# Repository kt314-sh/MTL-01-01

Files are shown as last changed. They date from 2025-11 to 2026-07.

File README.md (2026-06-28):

<div align="center">
<h1>📡 MTL-1: High-Power LoRa Node</h1>
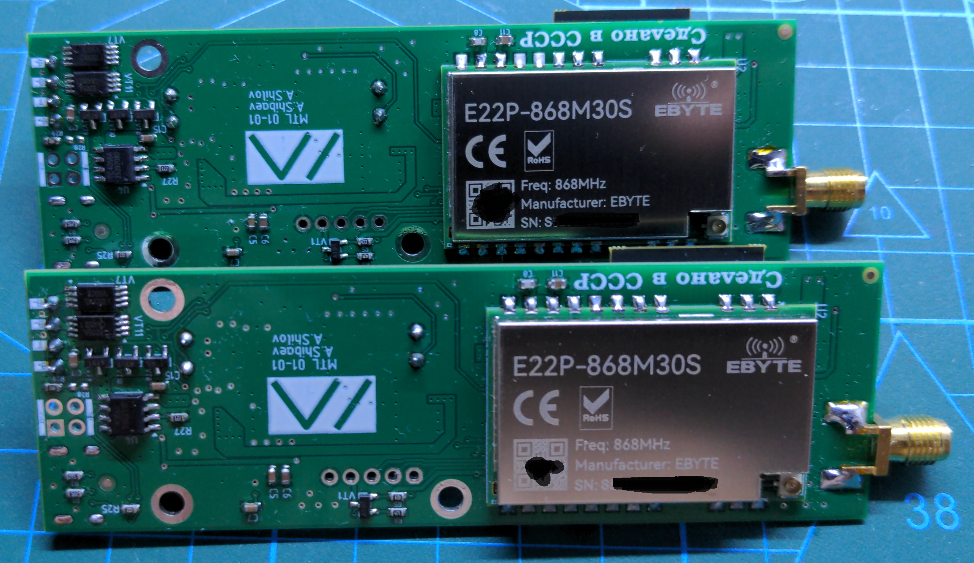
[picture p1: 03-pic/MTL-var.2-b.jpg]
 
  
<div align="left">
  
  # MTL-1
MTL-1 is a LoRa project based on ESP-32 s3 modules and [Ebyte](https://www.ebyte.com/) modules such as E22-xxxM30S, E22p-xxxM30S, E220-xxxM30S, E22-xxxM33S
Designed to work in [MeshCore](https://github.com/meshcore-dev ), [Meshtastic](https://github.com/meshtastic ), as a client and repeater.
- The project is almost fully compatible with Heltec v3, Heltec WSL3.
- 1A Standalone Linear Li-Ion Battery Charger
- Battery protection lithium-ion/polymer battery
- DC/DC up to 5V
- SMA connector
- GPIO
- 2 button. RESET, BOOT

 The device has proven itself well as a repeater and bridge 868/433
 
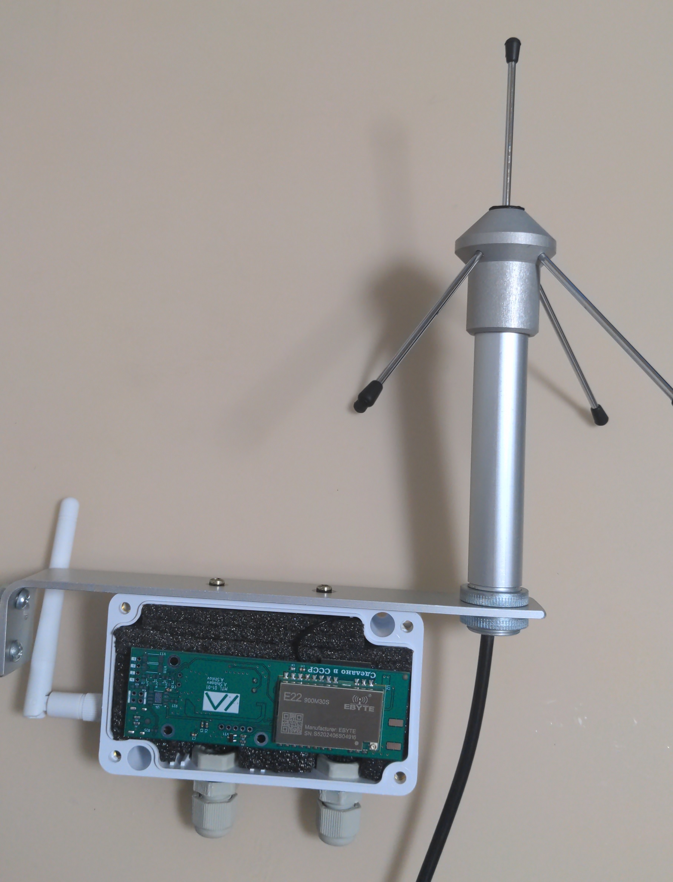
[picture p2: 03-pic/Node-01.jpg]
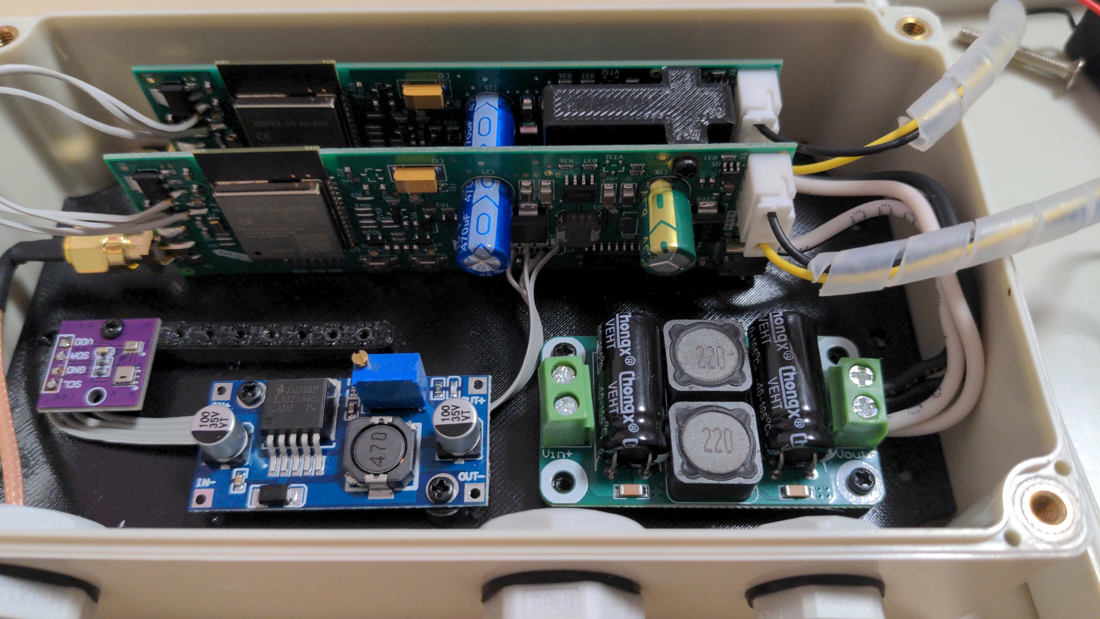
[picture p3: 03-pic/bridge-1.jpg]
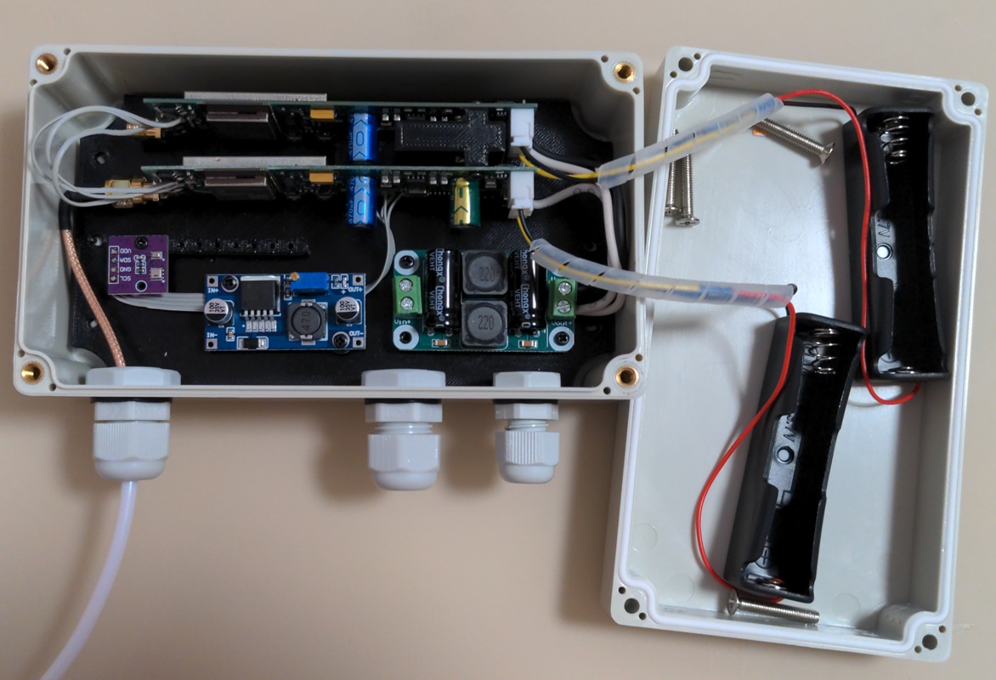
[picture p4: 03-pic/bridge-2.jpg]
    

### MTL-1 is available in three versions

#### Version 1. (not tested)
Support for Li-ion battery. When powered by USB, the DC Up converter is disconnected, and the e22 module receives a voltage of ~4.6V. When powered by the battery, DC Up is activated, and the e22 module receives a voltage of 5v.

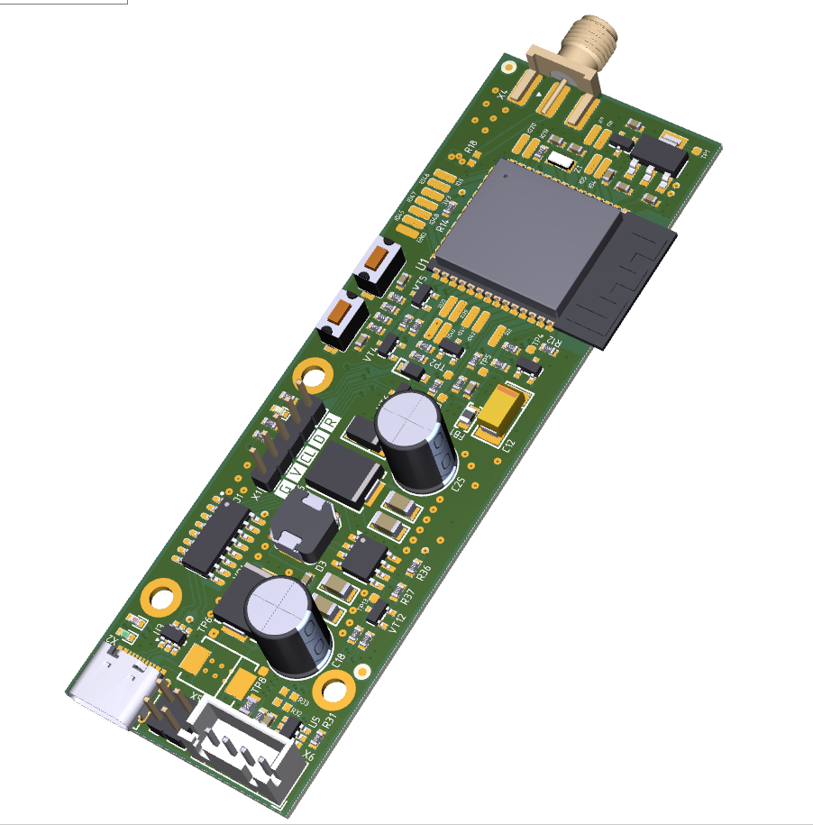
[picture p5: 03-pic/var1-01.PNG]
ver1T
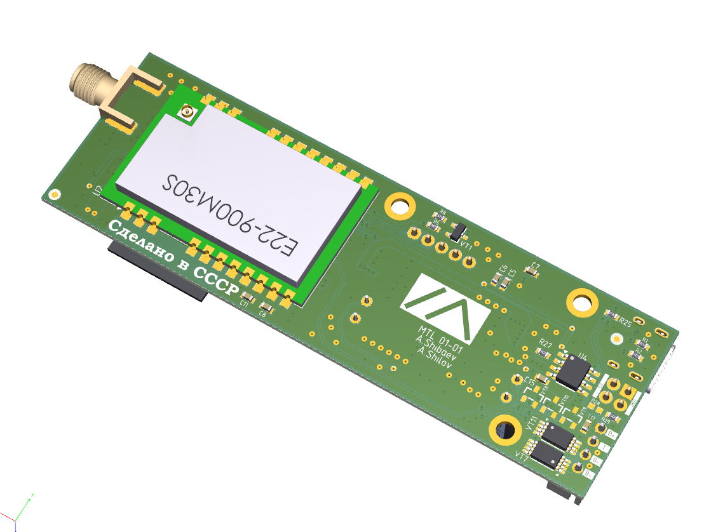
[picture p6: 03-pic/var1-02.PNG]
ver1B
 

#### Version 2
Support for Li-ion battery. When powered by USB, the DC Up converter is activated, and the e22 module receives a voltage of 5v. When powered by the battery, DC Up is activated, and the e22 module receives a voltage of 5v.

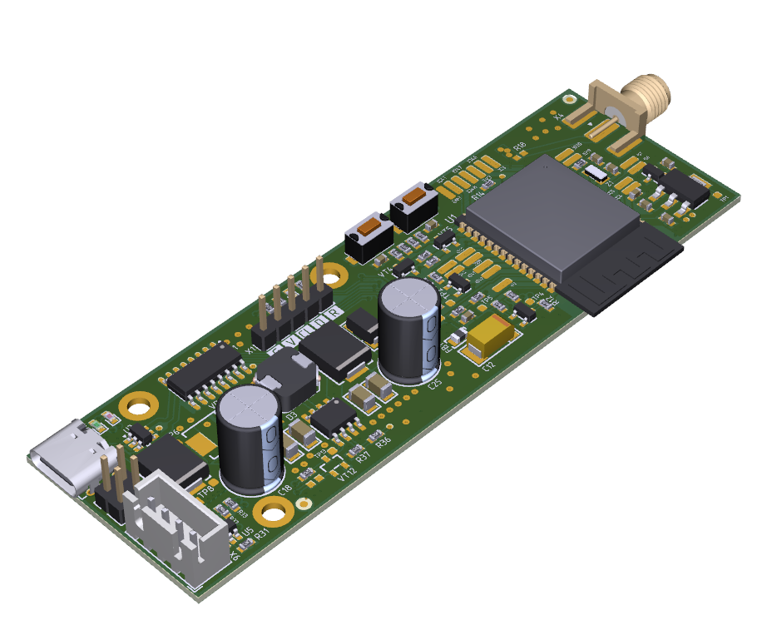
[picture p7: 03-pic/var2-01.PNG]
ver2T
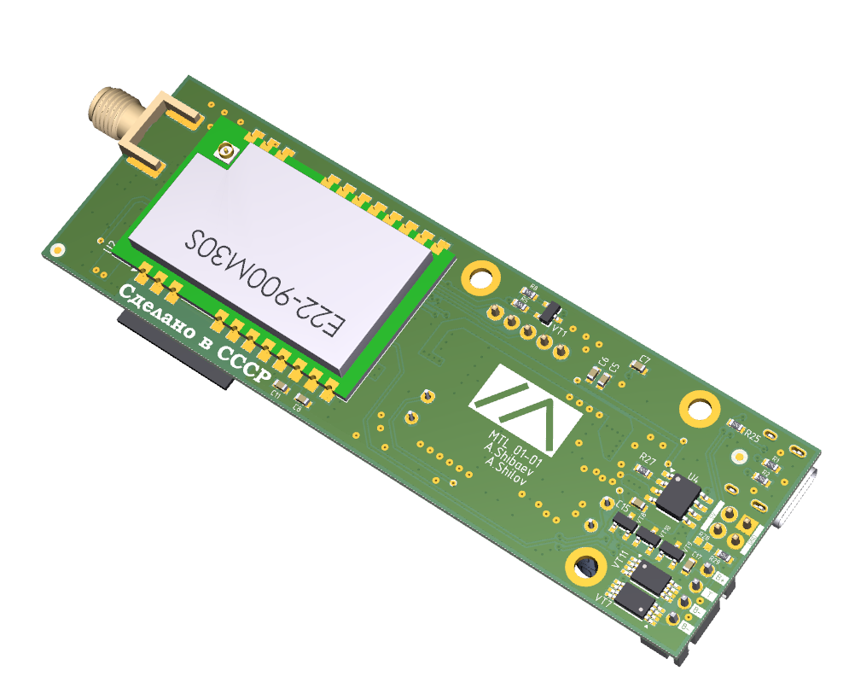
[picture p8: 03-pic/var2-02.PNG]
ver2B
 

#### Version 3
There is no Li-Ion battery support. When powered by USB, the e22 module receives a voltage of ~4.6V.

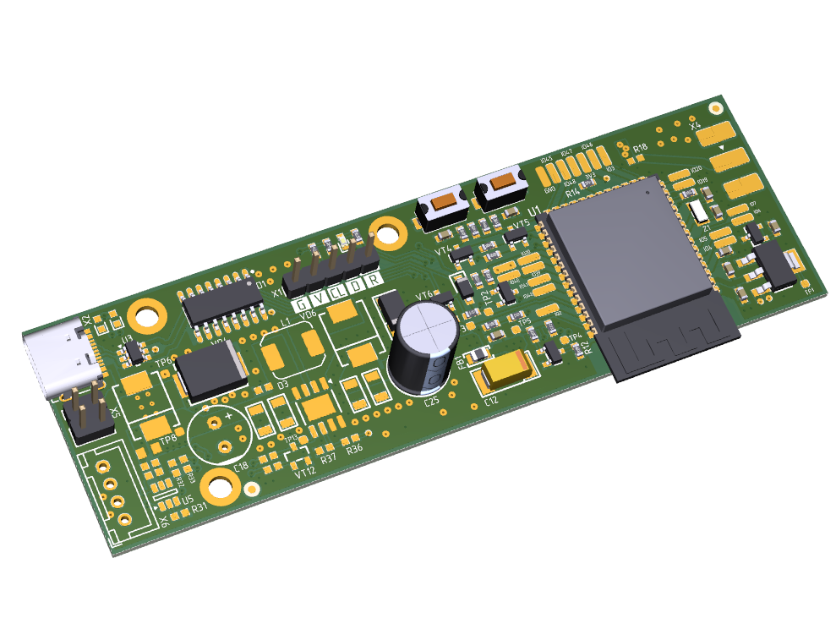
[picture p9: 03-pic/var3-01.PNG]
ver3T
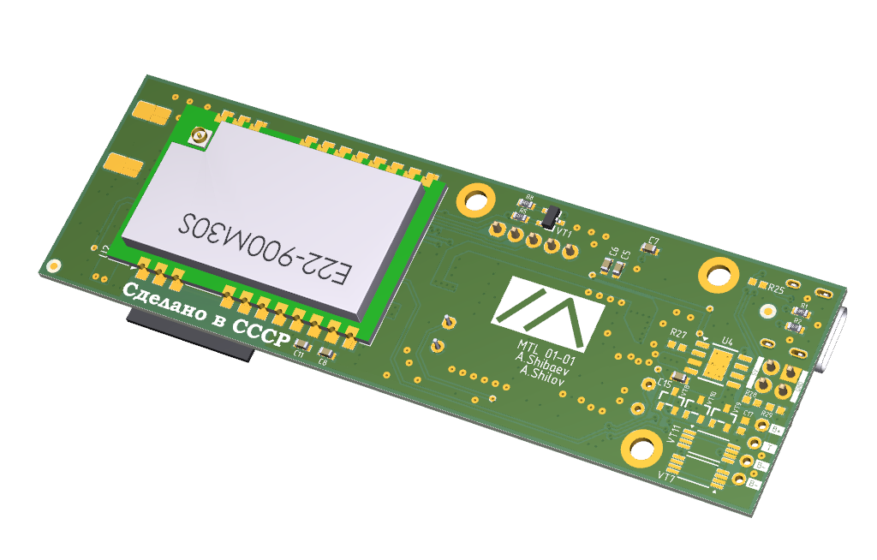
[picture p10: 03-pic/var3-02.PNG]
ver3B
 

### Power supply
The main power supply of the MTL-1 is provided via the "USB-C" or "X5" connectors, with a voltage of 5V, the recommended power supply current is 1.5...2A

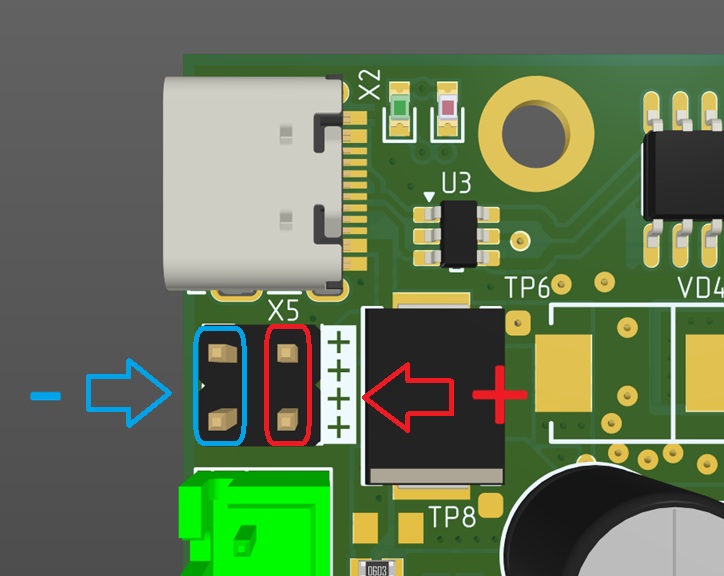
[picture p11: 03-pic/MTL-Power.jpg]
mtl1pwr


### Connecting a 3.7V Li-Ion battery (Version 1&2)
- To connect a battery without protection, use the "X6" connector. Maximum battery charge current 1A

- In the case of using a battery with protection, it is necessary to connect the +battery to the "Battery+" connector "X6", and the -battery to the "-" connector "X5".

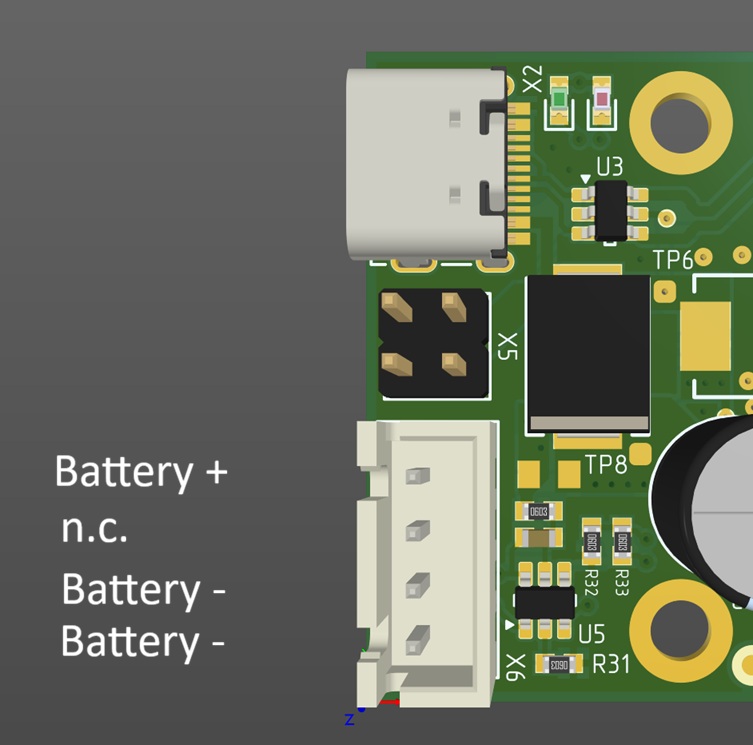
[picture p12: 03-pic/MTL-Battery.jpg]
mtlbtr


### Additional IO
Available IO: 2, 3, 4, 5, 6, 7, 19, 20, 38, 39, 40, 41, 42, 45, 46, 47, 48

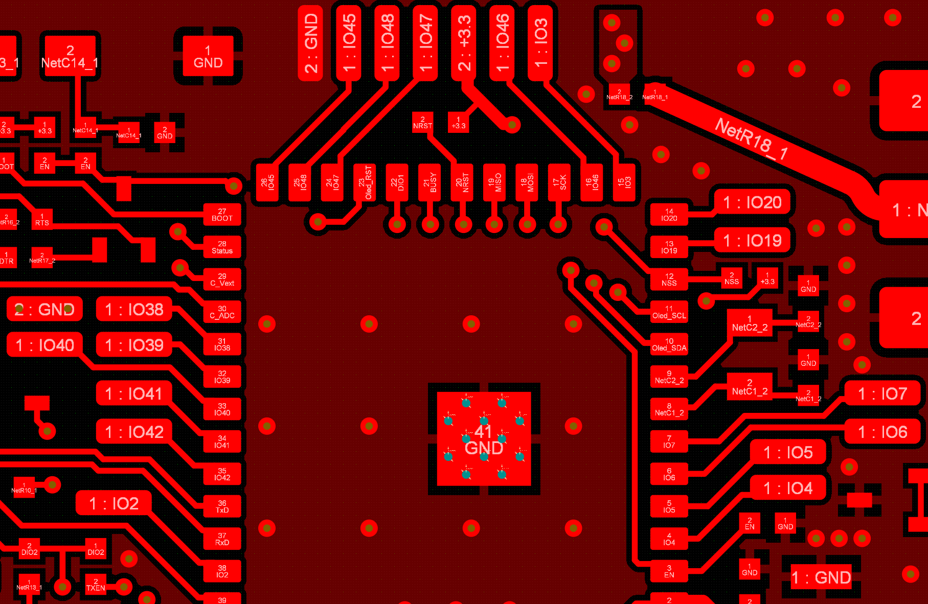
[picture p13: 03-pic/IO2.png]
mtlio1
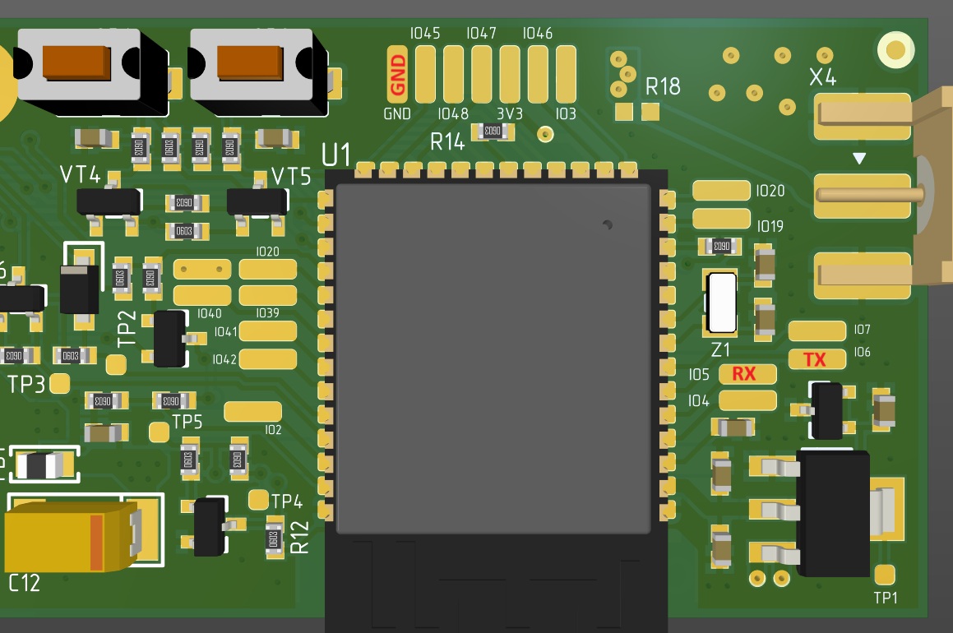
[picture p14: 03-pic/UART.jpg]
mtluart
 

### Connecting the antenna to IPEX
To use IPEX, the "R18" jumper must be removed

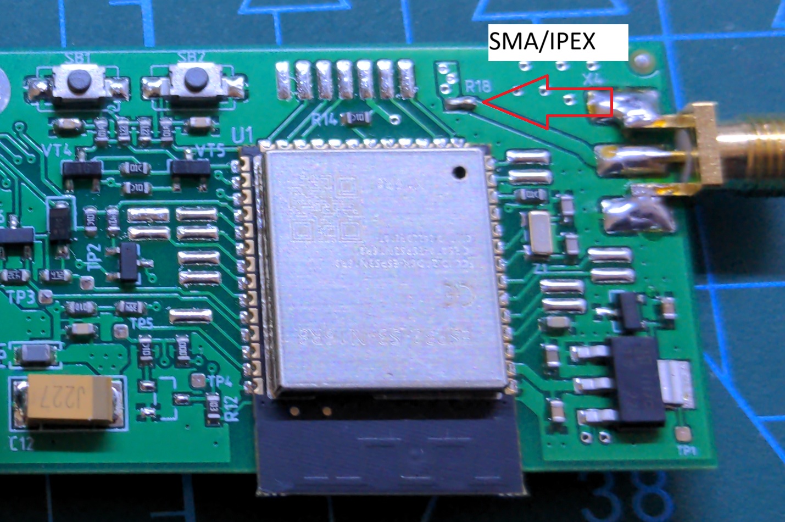
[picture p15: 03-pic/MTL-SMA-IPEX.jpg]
mtlsmaipex
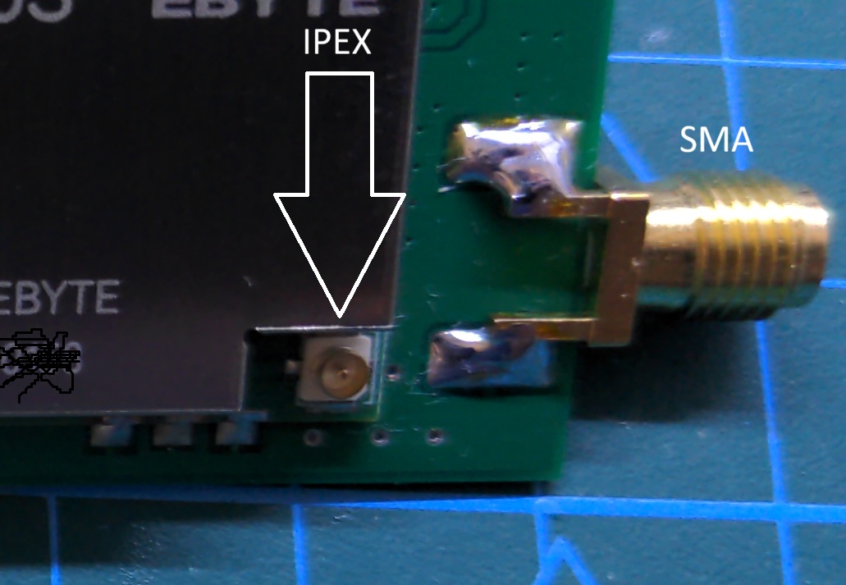
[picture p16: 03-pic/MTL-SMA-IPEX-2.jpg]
mtlsmaipex2
  

### Connecting an Oled display (SSD1306)
- G	GND
- V	+3.3v (Vcc)
- CL	i2c-SCL
- D	i2c-SDA

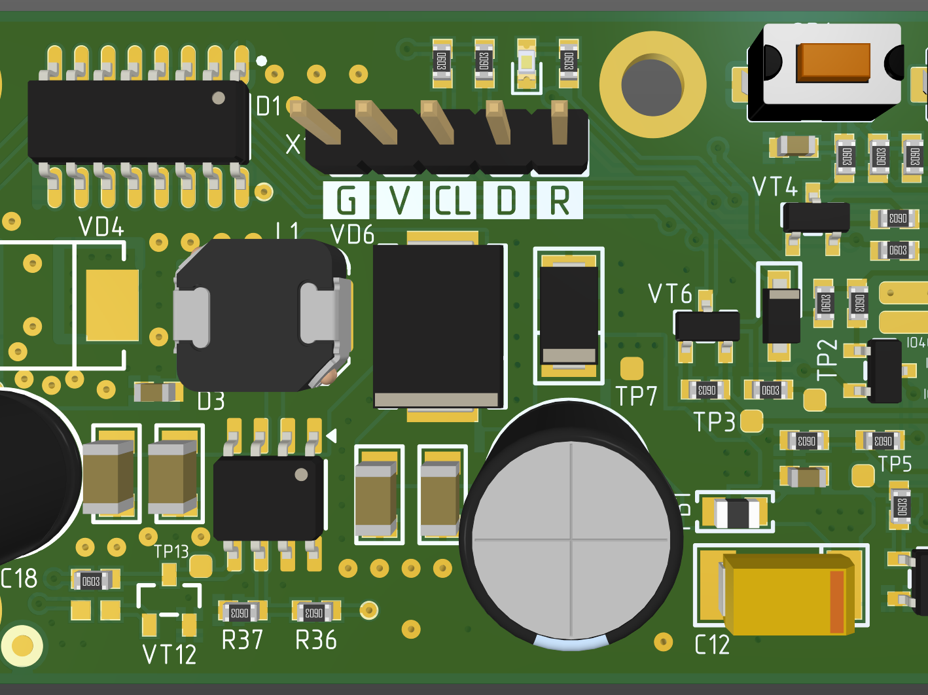
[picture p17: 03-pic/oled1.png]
mtloled1
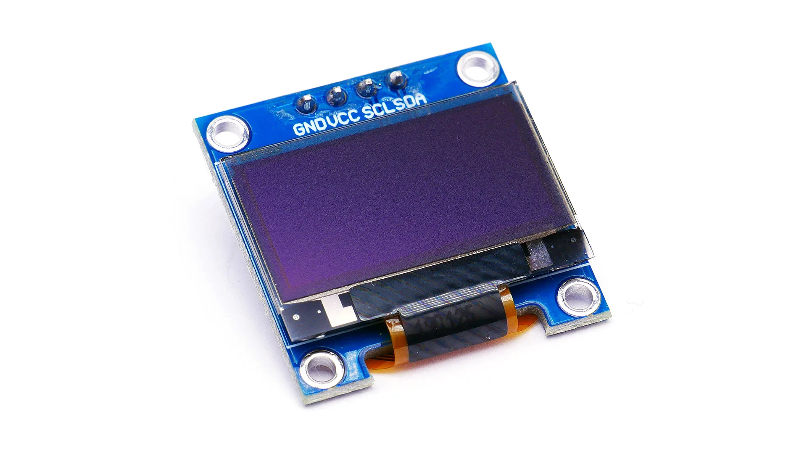
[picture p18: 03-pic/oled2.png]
mtloled2
  

### Driver CH340

Download driver [CH340.exe](https://www.wch-ic.com/downloads/CH341SER_EXE.html) [CH340.zip](https://www.wch-ic.com/downloads/CH341SER_ZIP.html) or [Github](https://github.com/jayfourjavier/INSTALL-CH340-ON-WINDOWS-11)

### Frequency range
#### 150-170Mhz
- e22-170m30s    SX1268  30dBm

#### 430Mhz
- e22p-433m30s   SX1268          30dBm
- e22-400m30s    SX1262, SX1268  30dBm (If S1262 Compatible with Heltec v3, Heltec WSL3)
- e22-400m33s    SX1268          33dBm
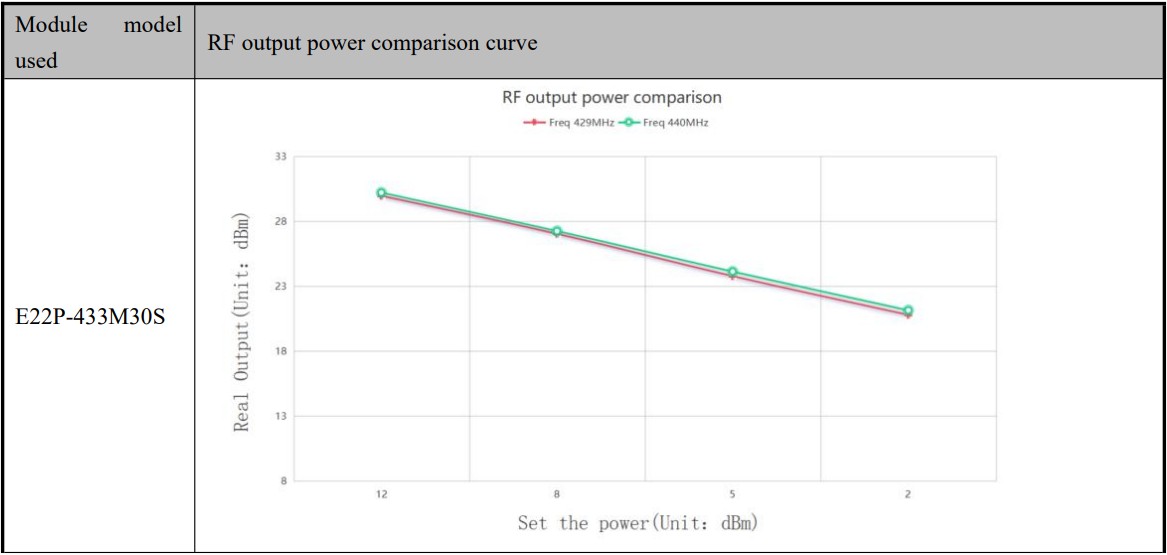
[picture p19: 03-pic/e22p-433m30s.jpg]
mtle22p433


#### 868-915Mhz
- e22p-868m30s   SX1262  31dBm  (Compatible with Heltec v3, Heltec WSL3)
- e22p-915m30s   SX1262  31dBm  (Compatible with Heltec v3, Heltec WSL3) 
- e22-900m30s    SX1262  30dBm  (Compatible with Heltec v3, Heltec WSL3)
- e22-900m33s    SX1262  33dBm

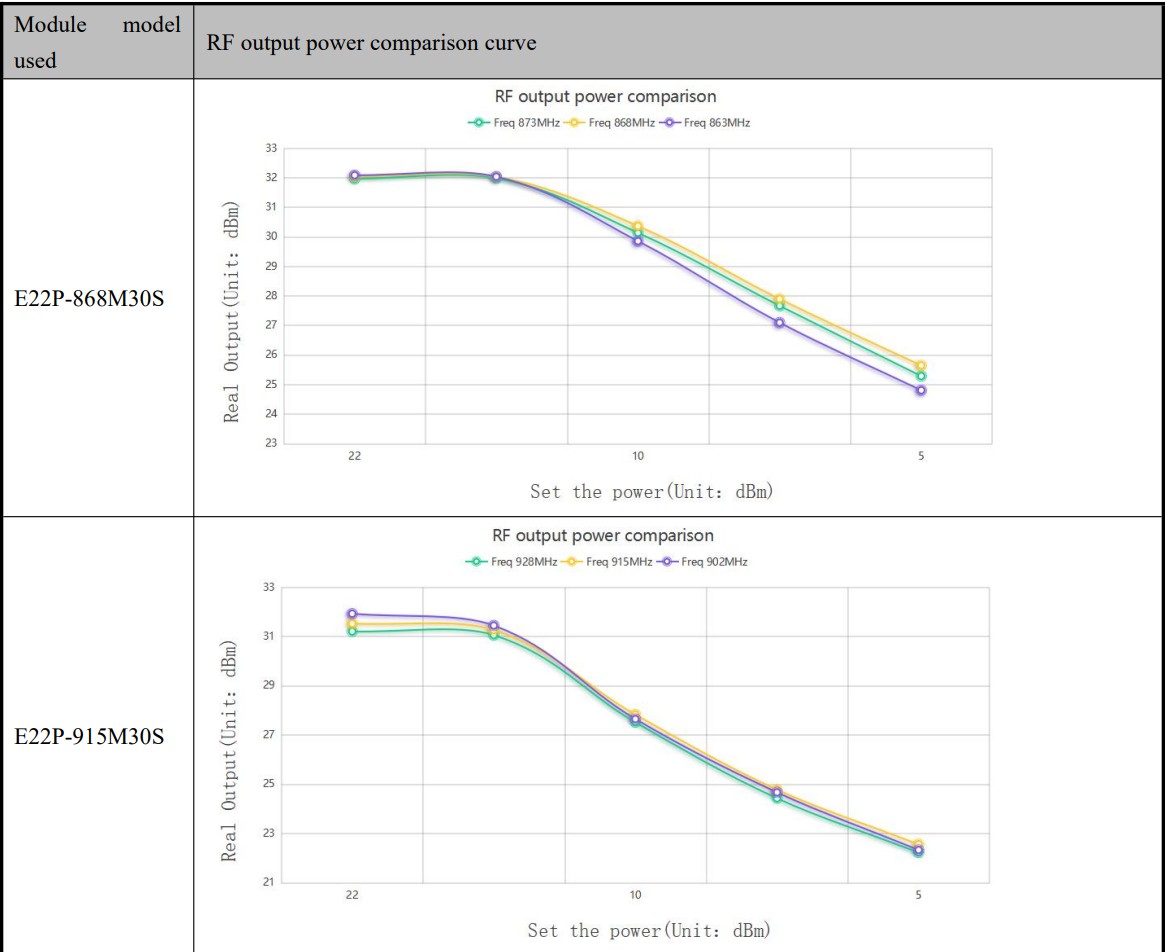
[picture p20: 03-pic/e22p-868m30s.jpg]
mtle22p868


### Case

- А good sealed casing made of Plastic sewer pipe with a diameter of 40-50mm
- The rainproof modem box VT-BOX9 with the antenna MOXON
- Rainproof case for Bridge Z10-7 158х90х60

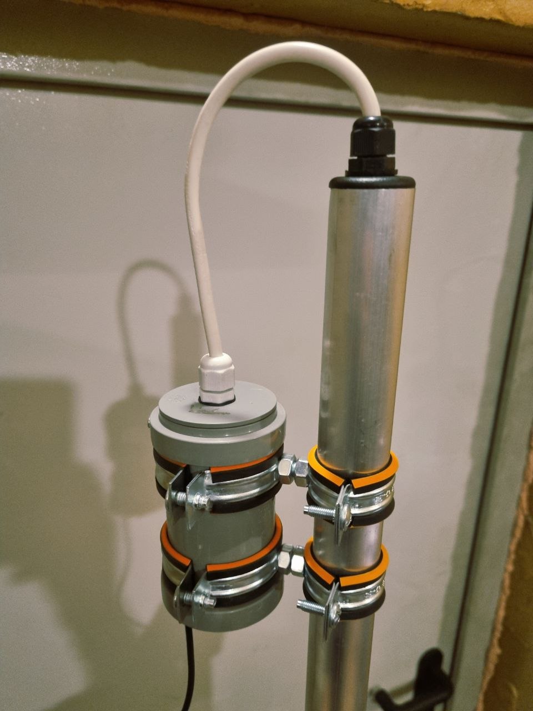
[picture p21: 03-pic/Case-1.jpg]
case1
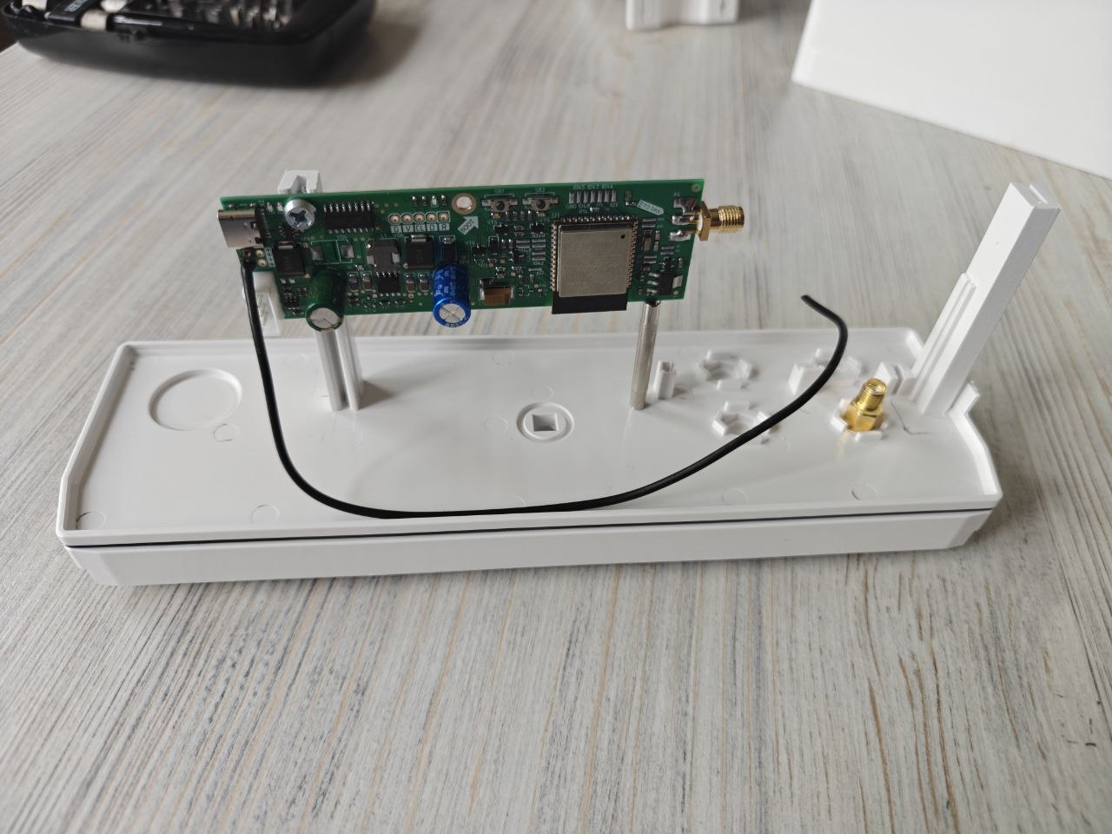
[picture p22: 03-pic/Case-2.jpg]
case2
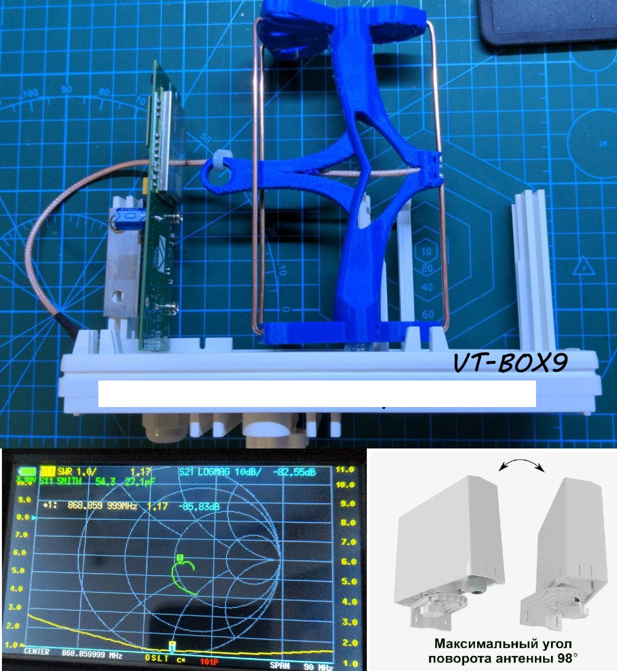
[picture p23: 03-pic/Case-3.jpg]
case3
  

### Repiters in use

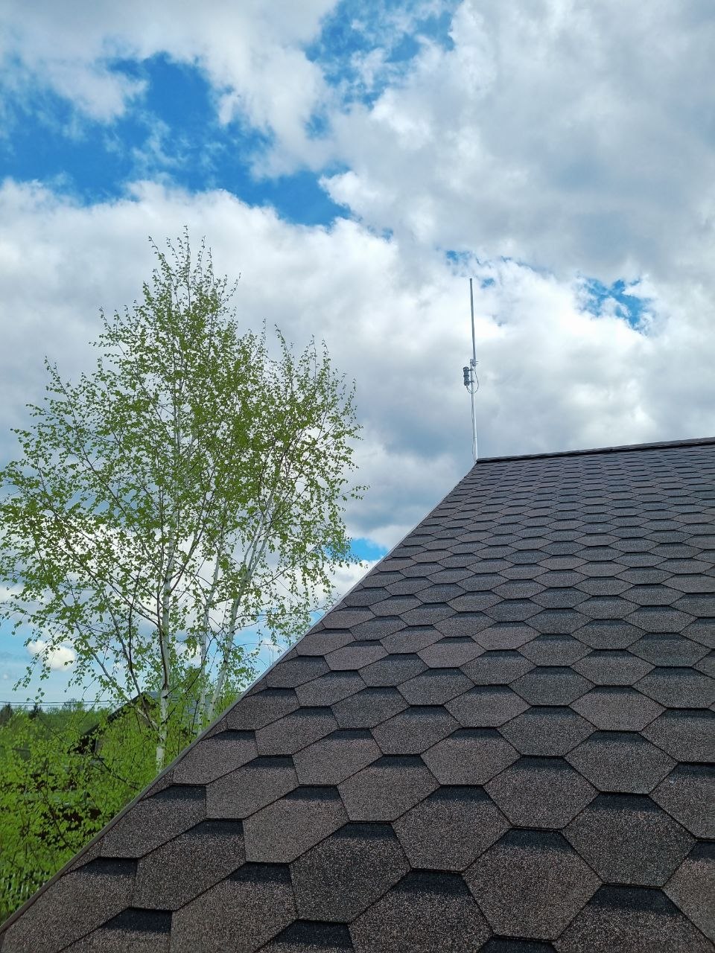
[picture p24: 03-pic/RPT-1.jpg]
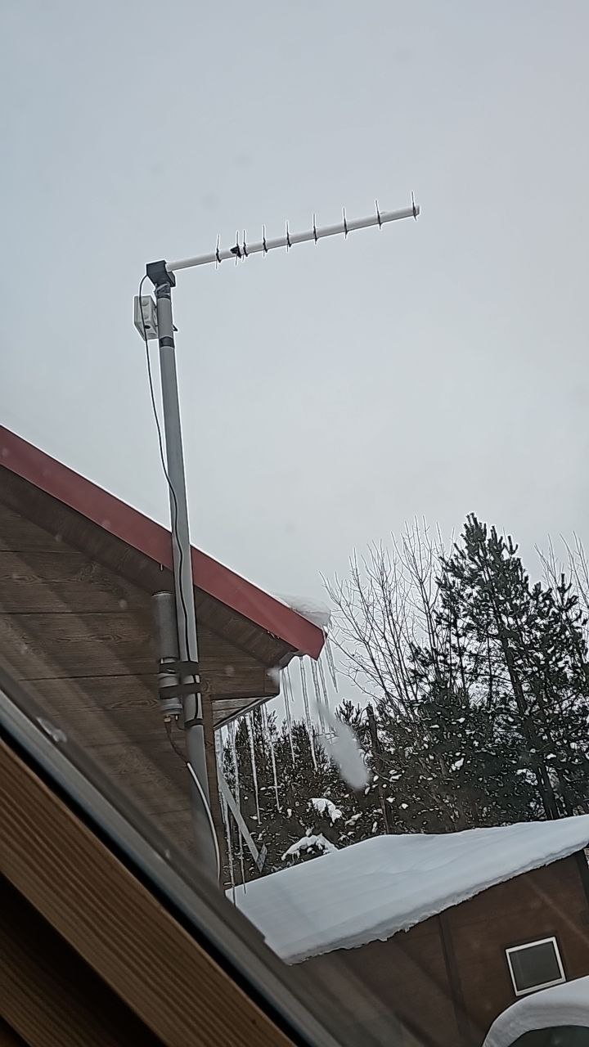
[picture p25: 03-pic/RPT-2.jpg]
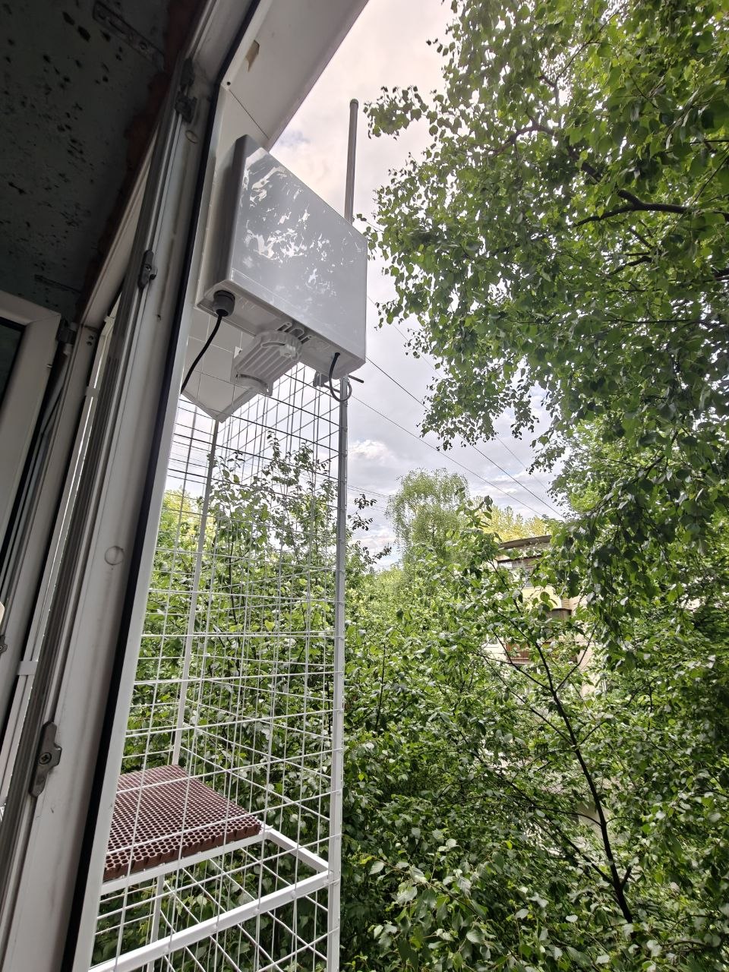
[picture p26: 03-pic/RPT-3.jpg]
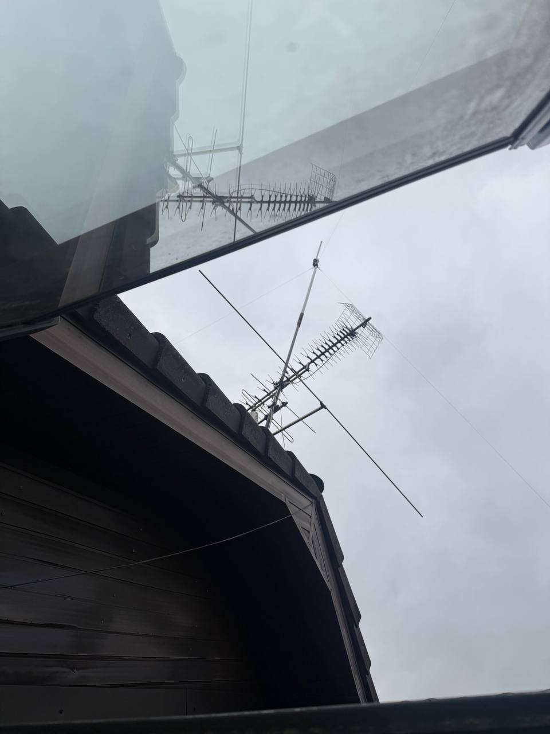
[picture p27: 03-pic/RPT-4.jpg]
rpt4
   

## Documentation
- GERBER [files](\01-PCB\Fabrication)
- Pick and Place [files](\01-PCB)
- Interactive scheme [BoM](\01-PCB)
- Datasheet [files](\02-datasheet)
- 3d model [STEP files](\04-3dmod)
- Mounting plate for case [Z10-7 158х90х60](\05-case\01-bridge)
- Instructions [RU](MTL-1_manual_04.2026.pdf)

### MeshCore SPB
- [MeshCore SPB](https://meshcore.spb.ru)
- [Telegram MeshCore SPB](https://t.me/meshcore_petersburg)

Additional description, see the link
https://github.com/vy52am0u/MTL

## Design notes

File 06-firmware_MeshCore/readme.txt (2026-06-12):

;add \variants\heltec_v3\target.h

#include <helpers/radiolib/CustomSX1268Wrapper.h>

;add \variants\heltec_v3\platformio.ini

[env:Heltec_v3_SX1268_repeater]
extends = Heltec_lora32_v3
build_flags =
  ${Heltec_lora32_v3.build_flags}
  -D USE_SX1268
  -D RADIO_CLASS=CustomSX1268
  -D WRAPPER_CLASS=CustomSX1268Wrapper
  -D DISPLAY_CLASS=SSD1306Display
  -D ADVERT_NAME='"MTL-1 433Mhz Repeater"'
  -D ADVERT_LAT=0.0
  -D ADVERT_LON=0.0
  -D ADMIN_PASSWORD='"password"'
  -D MAX_NEIGHBOURS=50
;  -D MESH_PACKET_LOGGING=1
;  -D MESH_DEBUG=1
  -D LORA_FREQ=433.0
  -D LORA_TX_POWER=12
build_src_filter = ${Heltec_lora32_v3.build_src_filter}
  +<helpers/ui/SSD1306Display.cpp>
  +<../examples/simple_repeater>
lib_deps =
  ${Heltec_lora32_v3.lib_deps}
  ${esp32_ota.lib_deps}
  bakercp/CRC32 @ ^2.0.0

[env:Heltec_v3_SX1268_repeater_bridge_rs232]
extends = Heltec_lora32_v3
build_flags =
  ${Heltec_lora32_v3.build_flags}
  -D USE_SX1268
  -D RADIO_CLASS=CustomSX1268
  -D WRAPPER_CLASS=CustomSX1268Wrapper
  -D DISPLAY_CLASS=SSD1306Display
  -D LORA_FREQ=433.0
  -D LORA_TX_POWER=12
  -D ADVERT_NAME='"MTL-1 UART Bridge"'
  -D ADVERT_LAT=0.0
  -D ADVERT_LON=0.0
  -D ADMIN_PASSWORD='"password"'
  -D MAX_NEIGHBOURS=50
  -D WITH_RS232_BRIDGE=Serial2
  -D WITH_RS232_BRIDGE_RX=5
  -D WITH_RS232_BRIDGE_TX=6
;  -D BRIDGE_DEBUG=1
;  -D MESH_PACKET_LOGGING=1
;  -D MESH_DEBUG=1
build_src_filter = ${Heltec_lora32_v3.build_src_filter}
  +<helpers/bridges/RS232Bridge.cpp>
  +<helpers/ui/SSD1306Display.cpp>
  +<../examples/simple_repeater>
lib_deps =
  ${Heltec_lora32_v3.lib_deps}
  ${esp32_ota.lib_deps}

[env:Heltec_v3_SX1268_repeater_bridge_espnow]
extends = Heltec_lora32_v3
build_flags =
  ${Heltec_lora32_v3.build_flags}
  -D RADIO_CLASS=CustomSX1268
  -D WRAPPER_CLASS=CustomSX1268Wrapper
  -D DISPLAY_CLASS=SSD1306Display
  -D LORA_FREQ=433.0
  -D LORA_TX_POWER=12
  -D DISPLAY_CLASS=SSD1306Display
  -D ADVERT_NAME='"MTL-1 ESPNow Bridge"'
  -D ADVERT_LAT=0.0
  -D ADVERT_LON=0.0
  -D ADMIN_PASSWORD='"password"'
  -D MAX_NEIGHBOURS=50
  -D WITH_ESPNOW_BRIDGE=1
;  -D BRIDGE_DEBUG=1
;  -D MESH_PACKET_LOGGING=1
;  -D MESH_DEBUG=1
build_src_filter = ${Heltec_lora32_v3.build_src_filter}
  +<helpers/bridges/ESPNowBridge.cpp>
  +<helpers/ui/SSD1306Display.cpp>
  +<../examples/simple_repeater>
lib_deps =
  ${Heltec_lora32_v3.lib_deps}
  ${esp32_ota.lib_deps}

[env:Heltec_v3_SX1268_companion_radio_usb]
extends = Heltec_lora32_v3
build_flags =
  ${Heltec_lora32_v3.build_flags}
  -I examples/companion_radio/ui-new
  -D RADIO_CLASS=CustomSX1268
  -D WRAPPER_CLASS=CustomSX1268Wrapper
  -D DISPLAY_CLASS=SSD1306Display
  -D LORA_FREQ=433.0
  -D LORA_TX_POWER=12
  -D MAX_CONTACTS=350
  -D MAX_GROUP_CHANNELS=40
  -D DISPLAY_CLASS=SSD1306Display
; NOTE: DO NOT ENABLE -->  -D MESH_PACKET_LOGGING=1
; NOTE: DO NOT ENABLE -->  -D MESH_DEBUG=1
build_src_filter = ${Heltec_lora32_v3.build_src_filter}
  +<helpers/ui/SSD1306Display.cpp>
  +<helpers/ui/MomentaryButton.cpp>
  +<../examples/companion_radio/*.cpp>
  +<../examples/companion_radio/ui-new/*.cpp>
lib_deps =
  ${Heltec_lora32_v3.lib_deps}
  densaugeo/base64 @ ~1.4.0

[env:Heltec_v3_SX1268_companion_radio_ble]
extends = Heltec_lora32_v3
build_flags =
  ${Heltec_lora32_v3.build_flags}
  -I examples/companion_radio/ui-new
  -D RADIO_CLASS=CustomSX1268
  -D WRAPPER_CLASS=CustomSX1268Wrapper
  -D DISPLAY_CLASS=SSD1306Display
  -D LORA_FREQ=433.0
  -D LORA_TX_POWER=12
  -D MAX_CONTACTS=350
  -D MAX_GROUP_CHANNELS=40
  -D DISPLAY_CLASS=SSD1306Display
  -D BLE_PIN_CODE=123456   ; dynamic, random PIN
  -D AUTO_SHUTDOWN_MILLIVOLTS=3400
  -D BLE_DEBUG_LOGGING=1
  -D OFFLINE_QUEUE_SIZE=256
;  -D MESH_PACKET_LOGGING=1
;  -D MESH_DEBUG=1
build_src_filter = ${Heltec_lora32_v3.build_src_filter}
  +<helpers/ui/SSD1306Display.cpp>
  +<helpers/ui/MomentaryButton.cpp>
  +<helpers/esp32/*.cpp>
  +<../examples/companion_radio/*.cpp>
  +<../examples/companion_radio/ui-new/*.cpp>
lib_deps =
  ${Heltec_lora32_v3.lib_deps}
  densaugeo/base64 @ ~1.4.0

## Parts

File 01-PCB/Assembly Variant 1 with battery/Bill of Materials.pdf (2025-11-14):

Страница 1 из 3

Наименование проекта | MTL 01-01 | 14.11.2025 12:34
Исполнение | Variant 1 with battery
Manufacturer 1 | Name | Description | Designator | Quantity
Yageo Group | CC0603BRNPO9BN5R6 | Керамический ЧИП-конденсатор, 0603, 5.6 пФ, 50 В, NP0, 0.1pF | C1, C2 | 2
Yageo Group | CC0603KRX5R7BB475 | Керамический ЧИП-конденсатор, 0603, 4.7 мкФ, 16 В, X5R, 10% | C3, C5, C11, C17, C22 | 5
Yageo Group | CC0603JRX7R9BB104 | Керамический ЧИП-конденсатор, 0603, 100 нФ, 50 В, X7R, 5% | C4, C6, C7, C9, C15, C16 | 6
Yageo Group | CC0603JRNPO9BN102 | Керамический ЧИП-конденсатор, 0603, 1 нФ, 50 В, NP0, 5% | C8, C13, C14 | 3
Yageo Group | CC0603JRX7R9BB103 | Керамический ЧИП-конденсатор, 0603, 10 нФ, 50 В, X7R, 5% | C10 | 1
KEMET | T491C476K016AT | Танталовый ЧИП-конденсатор, типоразмер C, 47 мкФ, 16 В, 20% | C12 | 1
Hitano | EHR471M16BA | Конденсатор алюминиевый электролитический, 8x12 мм, 3.5 мм, 470 мкФ, 16 В, 20% | C18, C25 | 2
Samsung Electro-Mechanics | CL31B106KAHNNNE | Керамический ЧИП-конденсатор, 1206, 10 мкФ, 25 В, X7R, 10% | C19, C20, C23, C24 | 4
Samsung Electro-Mechanics | CL10B105KB8NQNC | Керамический ЧИП-конденсатор, 0603, 1 мкФ, 50 В, X7R, 10% | C21 | 1
WCH | CH340C | Интерфейс, преобразователь USB-UART | D1 | 1
Tae Jin Technology | LM1117GS-3.3 | Линейный стабилизатор, 3.3 В, 1 А | D2 | 1
XySemi | XR2981 | Повышающий DC/DC преобразователь, вх. 2.7..3.3 В, вых. 24 В | D3 | 1
Murata | BLM21PG121SH1D | Ферритовый ЧИП-фильтр, 0805, 120 Ом @ 100 МГц, 25%, 3 А, 30 мОм | FB1 | 1
HongliTronic | HL-PST-1608S22OC | Светодиод, 0603, оранжевый | HL1 | 1
Lite-On | LTST-C190KRKT | Светодиод, 0603, красный | HL2 | 1
HongliTronic | HL-PST-1608S11GC | Светодиод, 0603, зелёный | HL3 | 1
Yageo Group | RC0603FR-070RL | ЧИП-резистор, 0603, 0 Ом, 1%, 0.1 Вт | J1, R29 | 2
TDK | SPM6530T-2R2M | Индуктивность проволочная, SPM6530, 2.2 мкГн @ 100 кГц, 8.2 А, 20%, 19.1 мОм | L1 | 1
Yageo | RC0603FR-075K1L | ЧИП-резистор, 0603, 5.1 кОм, 1%, 0.1 Вт | R1, R2 | 2
Yageo Group | RC0603FR-0710KL | ЧИП-резистор, 0603, 10 кОм, 1%, 0.1 Вт | R3-R6, R12-R17, R19, R20, R35 | 13
Yageo Group | RC0603FR-07470RL | ЧИП-резистор, 0603, 470 Ом, 1%, 0.1 Вт | R7-R9, R21, R22 | 5

Страница 2 из

3

Yageo | RC0603FR-07390KL | ЧИП-резистор, 0603, 390 кОм, 1%, 0.1 Вт | R10 | 1
Yageo Group | RC0603FR-07100KL | ЧИП-резистор, 0603, 100 кОм, 1%, 0.1 Вт | R11 | 1
Yageo Group | RC0603FR-074K7L | ЧИП-резистор, 0603, 4.7 кОм, 1%, 0.1 Вт | R23, R24, R34 | 3
Yageo Group | RC0603FR-071KL | ЧИП-резистор, 0603, 1 кОм, 1%, 0.1 Вт | R25, R31 | 2
Yageo Group | RC0603FR-07100RL | ЧИП-резистор, 0603, 100 Ом, 1%, 0.1 Вт | R26 | 1
Yageo Group | RC0603FR-071K2L | ЧИП-резистор, 0603, 1.2 кОм, 1%, 0.1 Вт | R27 | 1
Yageo Group | RC0805FR-070RL | ЧИП-резистор, 0805, 0 Ом, 1%, 0.125 Вт | R30 | 1
Yageo Group | RC0603FR-0733KL | ЧИП-резистор, 0603, 33 кОм, 1%, 0.1 Вт | R36 | 1
Yageo Group | RC0603FR-0711KL | ЧИП-резистор, 0603, 11 кОм, 1%, 0.1 Вт | R37 | 1
Diptronics | DTSM-31N-V | Кнопка тактильная, миниатюрная, SMD, 12 В, 50 мА | SB1, SB2 | 2
| ESP32-S3-WROOM-1 | Модуль связи | U1 | 1
| E22-900M30S | Приёмопередатчик LoRa | U2 | 1
STMicroelectro nics | USBLC6-2SC6 | Сборка защитная, TVS-диоды, 5.2 В | U3 | 1
TOPPOWER | TP4056-42-ESOP8 | Контроллер заряда | U4 | 1
PUOLOP | DW01A | Контроллер литий-ионного аккумулятора | U5 | 1
Nexperia | BAT54H | Диод Шоттки, 30 В, 200 мА | VD1 | 1
Yangjie Electronic Technology | SS54 | Диод Шоттки, 40 В, 5 А | VD4, VD6 | 2
Nexperia | PESD3V3S2UT | Сдвоенный однонаправленный ESD-диод, 3.3 В | VD5 | 1
Yangjie Electronic Technology | SMAJ5.0A | Однонаправленный TVS-диод, 5 В | VD7 | 1
Alpha & Omega Semiconductor | AO3401 | Транзистор, P-канал, -30 В, -4 А | VT1, VT2 | 2
Nexperia | BC847C | Транзистор, NPN, 45 В, 100 мА | VT3-VT5, VT12 | 4
Nexperia | BSS138P | Транзистор, N-канал, 60 В, 360 мА | VT6 | 1
Fortune Semiconductor | FS8205A | Транзисторная сборка, 2N-канальный, 20 В/5 А | VT7, VT11 | 2
Connfly | DS1021-1X5 | Вилка на плату однорядная, прямая, 5 контактов, шаг 2.54 мм | X1 | 1
Connfly | DS1144-07 | Разъём USB Type-C угловой, 16 контактов | X2 | 1
Connfly | DS1158-03-01SV | Разъём SMA | X4 | 1
Connfly | DS1021-2x2 | Вилка на плату двухрядная, прямая, 4 контакта, шаг 2.54 мм | X5 | 1
JST | B4B-XH-A | Вилка на плату, 4 контакта, шаг 2.5мм, серия XH | X6 | 1

Страница 3 из 3

NDK | NX3215SA-32.768K-STD-
MUA-8 | Резонатор кварцевый, 3215, 32.768 кГц, 12.5 пФ, 20ppm | Z1 | 1

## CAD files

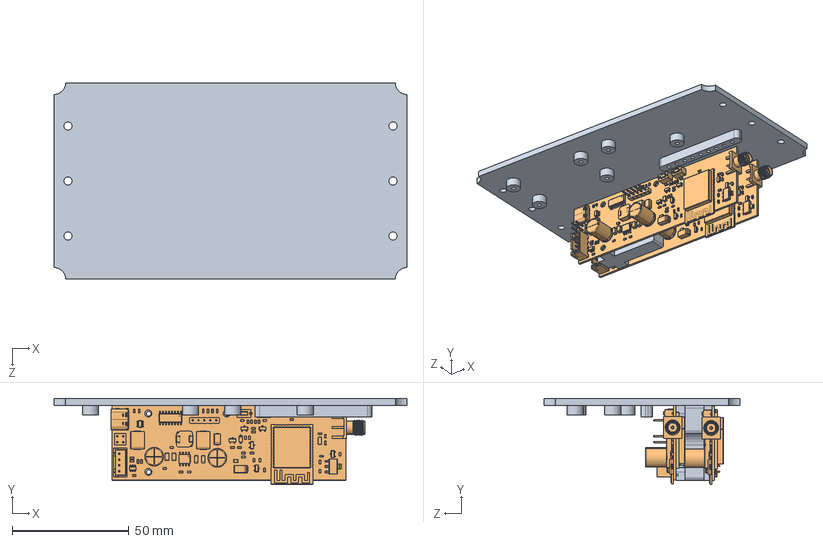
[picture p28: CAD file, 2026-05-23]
05-case/01-bridge/cad/Z10-7_158х90х60.SLDASM
151.0 x 36.8 x 84.0 mm
Шасси
MTL-01-01-var2.step x 2

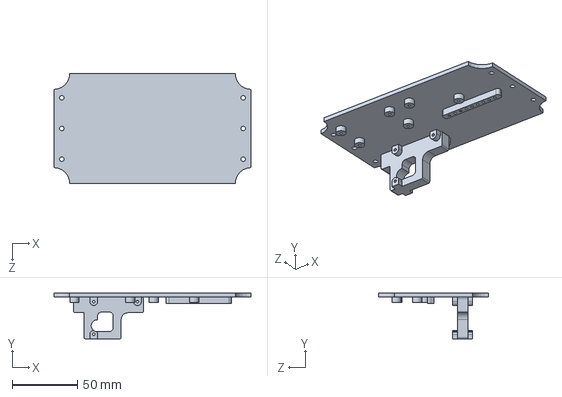
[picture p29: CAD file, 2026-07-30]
05-case/01-bridge/cad/Шасси2.SLDPRT
151.0 x 35.0 x 84.0 mm

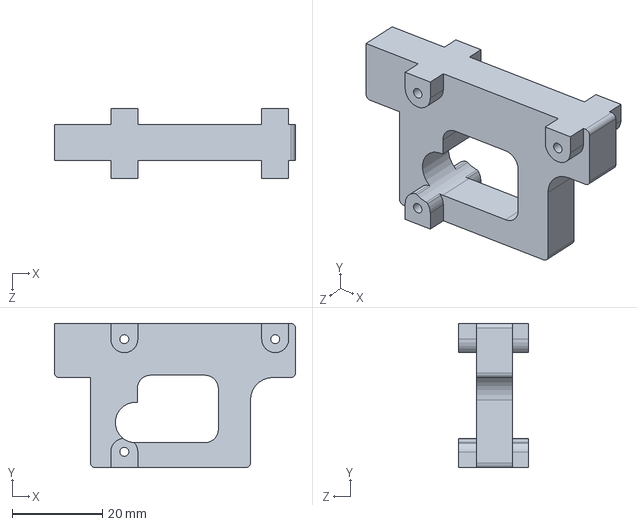
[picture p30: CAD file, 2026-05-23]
05-case/01-bridge/cad/Шасси1.SLDPRT
53.5 x 32.0 x 15.5 mm

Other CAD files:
05-case/01-bridge/cad/Шасси.SLDPRT
05-case/01-bridge/cad/Шасси2.STL
05-case/01-bridge/stl/Z10-7_158х90х60.3mf
05-case/01-bridge/stl/Z10-7_158х90х60.STL
05-case/01-bridge/stl/Шасси1.STL

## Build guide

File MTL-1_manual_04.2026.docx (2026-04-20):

# MTL-1


Содержание

1. Описание…………………………………………………………………….. 2
2. Подключение питания………………………………………………… 4
3. Подключение АКБ……………..………………………………………… 5
4. Дополнительные вводы-выводы……………………………….. 6
5. Подключение антенны к IPEX…………….……………………….. 7
6. Подключение Oled дисплея………………………………………… 7
7. Установка драйвера…………………………………………………….. 8
8. Установка Meshcore через Web Flasher……………………….10
9. Установка Meshcore через Flash download tool…………..13

MTL-1 это обучающий проект LoRa, основан на модулях ESP-32 s3 и модулях таких как E22-xxxM30S, E22p-xxxM30S, E220-xxxM30S, E22-xxxM33S

Проект практически полностью совместим с Heltec v3, Heltec WSL3.

Документация на проект

https://github.com/kt314-sh/MTL-01-01

https://github.com/vy52am0u/MTL

MTL-1 Существует в трёх вариантах исполнения

Вариант 1. (не тестировался)

Поддержка Li-Ion АКБ. При питании от USB, преобразователь DC Up отключен, на модуль e22 поступает напряжение ~4.6v. При питании от АКБ, DC Up задействован, на модуль e22 поступает напряжение 5v.

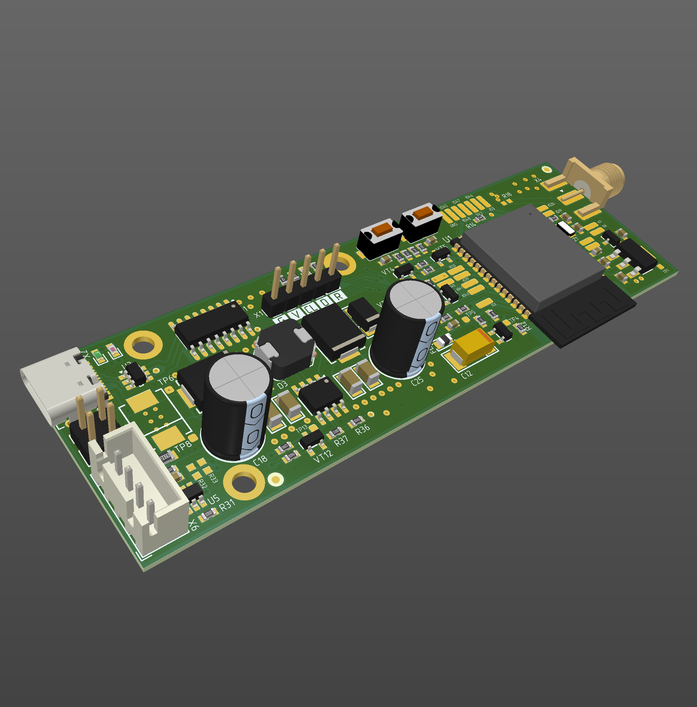
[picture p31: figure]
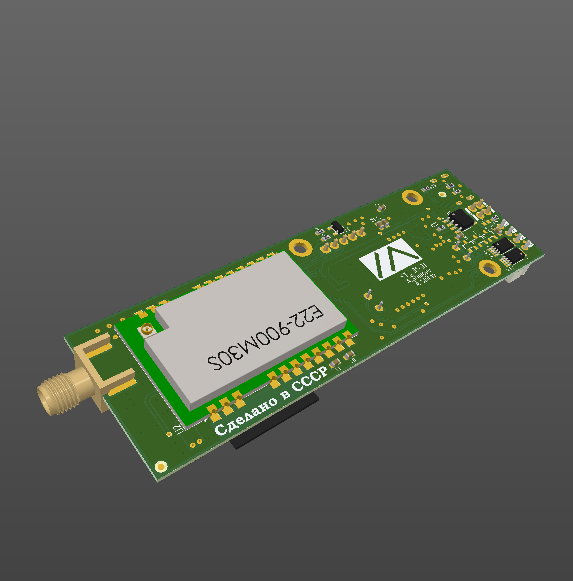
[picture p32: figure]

Вариант 2.

Поддержка Li-Ion АКБ. При питании от USB, преобразователь DC Up задействован, на модуль e22 поступает напряжение 5v. При питании от АКБ, DC Up задействован, на модуль e22 поступает напряжение 5v.

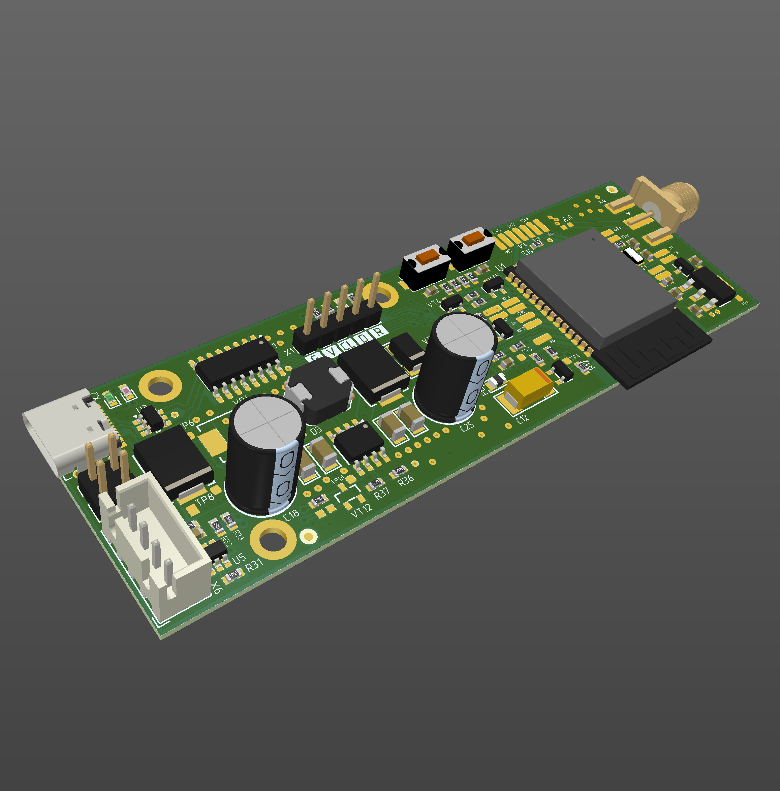
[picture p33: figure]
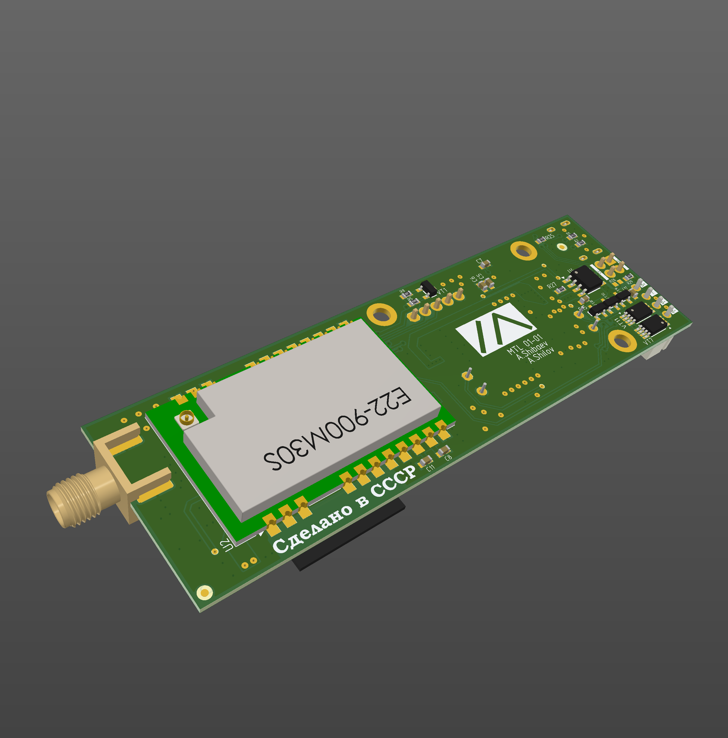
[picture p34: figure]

Вариант 3.

Отсутствует поддержка Li-Ion АКБ. При питании от USB, на модуль e22 поступает напряжение ~4.6v.

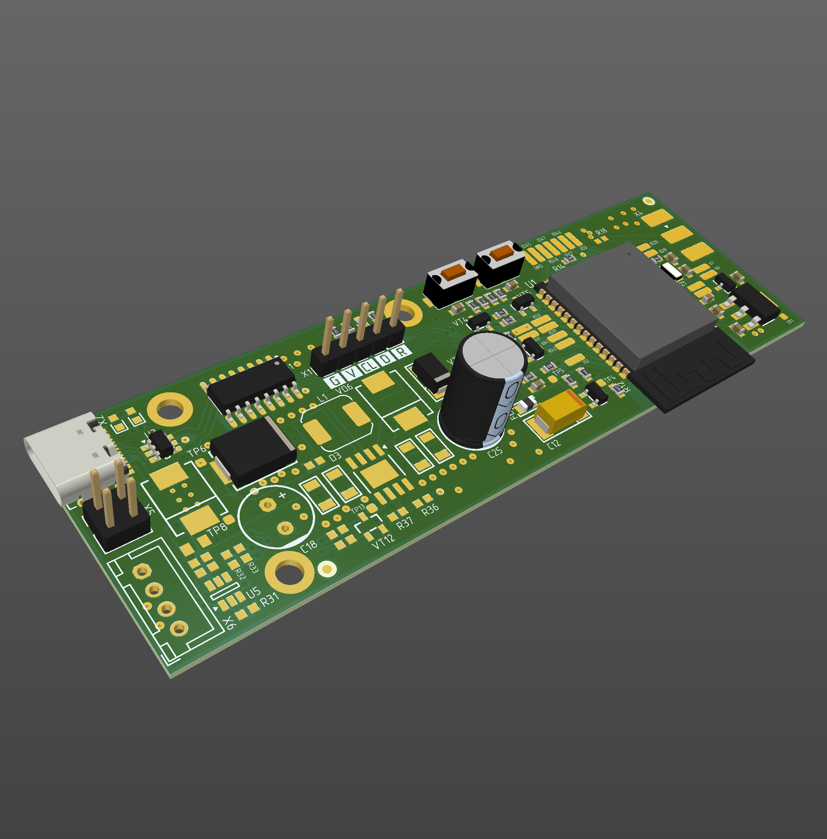
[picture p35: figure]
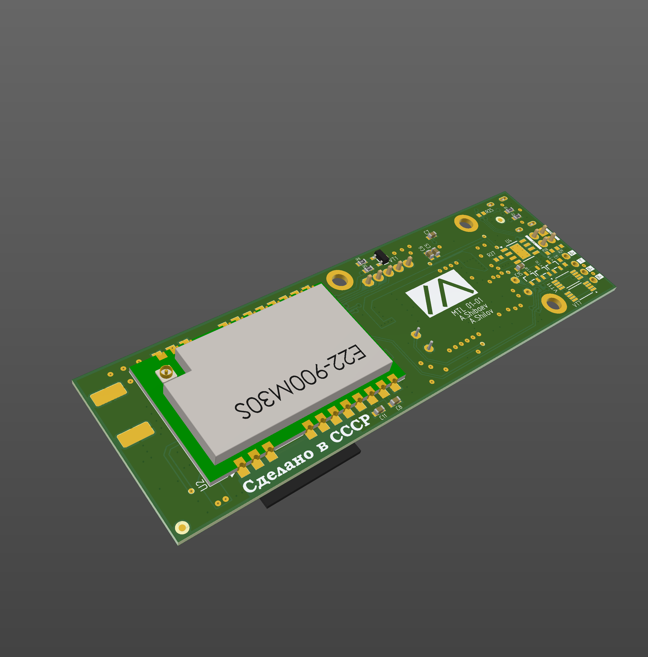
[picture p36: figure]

Подключение питания(Вариант 1,2,3)

Основное питание MTL-1 осуществляется через разъемы «USB-C» либо «X5», напряжением 5В, рекомендуемый ток источника питания 1.5...2А

Подключение Li-Ion АКБ 3.7В (Вариант 1,2)

Для подключения АКБ без защиты, используем разъему «X6». Максимальный ток заряда АКБ 1А

В случае использования АКБ с защитой, то необходимо подключить +АКБ к «Battery+» разъема «X6», а -АКБ к «-» разъема «X5».

Дополнительные IO

Доступные IO 2, 3, 4, 5, 6, 7, 19, 20, 38, 39, 40, 41, 42, 45, 46, 47, 48

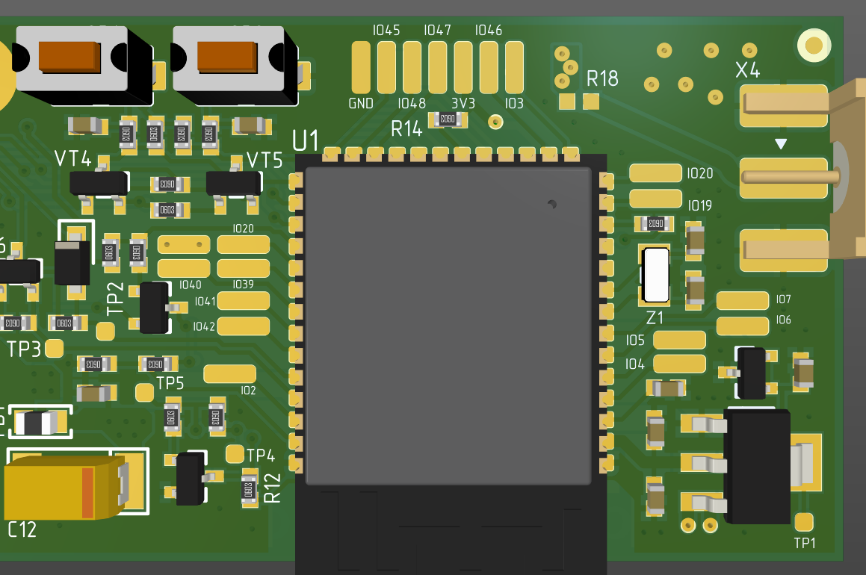
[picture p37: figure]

Подключение антенны к IPEX

Для использования IPEX, необходимо удалить перемычку «R18»

Подключение Oled дисплея (SSD1306)

G GND

V +3.3v (Vcc)

CL i2c-SCL

D i2c-SDA

Установка драйвера

1. Скачайте драйвер СH340

https://www.wch-ic.com/downloads/CH341SER_EXE.html

https://www.wch-ic.com/downloads/CH341SER_ZIP.html

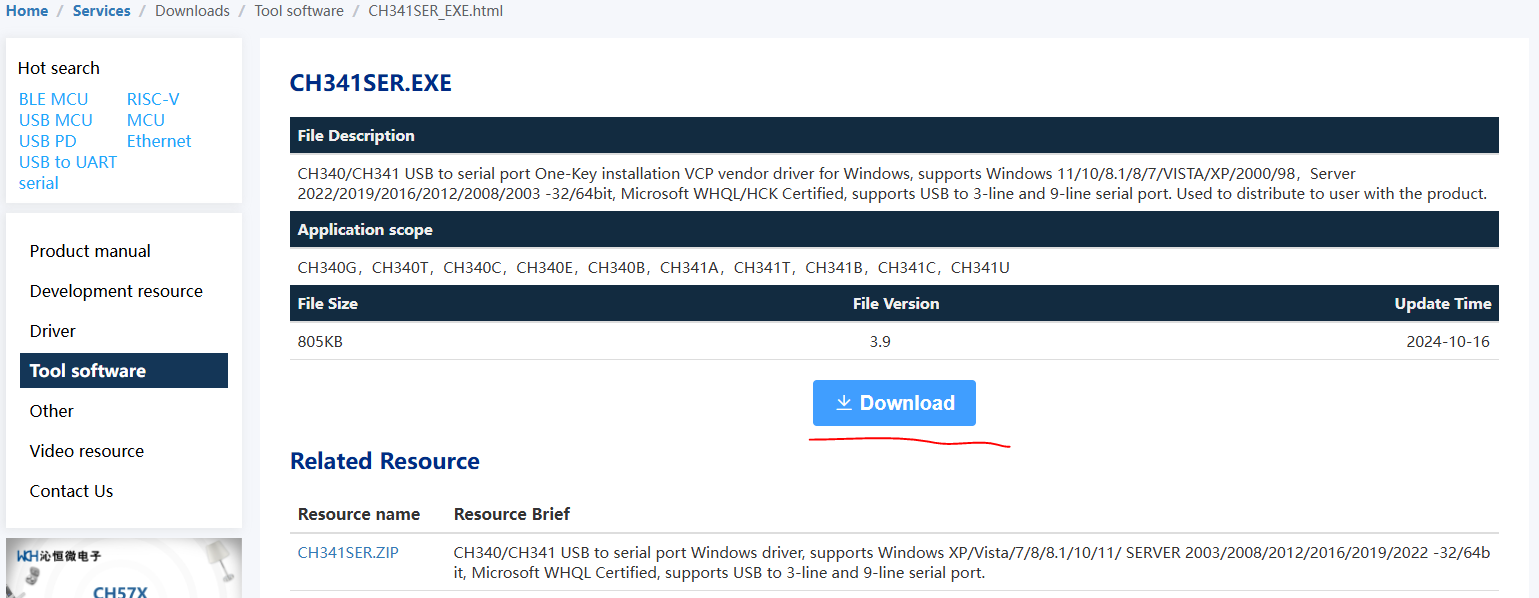
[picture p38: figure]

Или с Git Hub

https://github.com/jayfourjavier/INSTALL-CH340-ON-WINDOWS-11

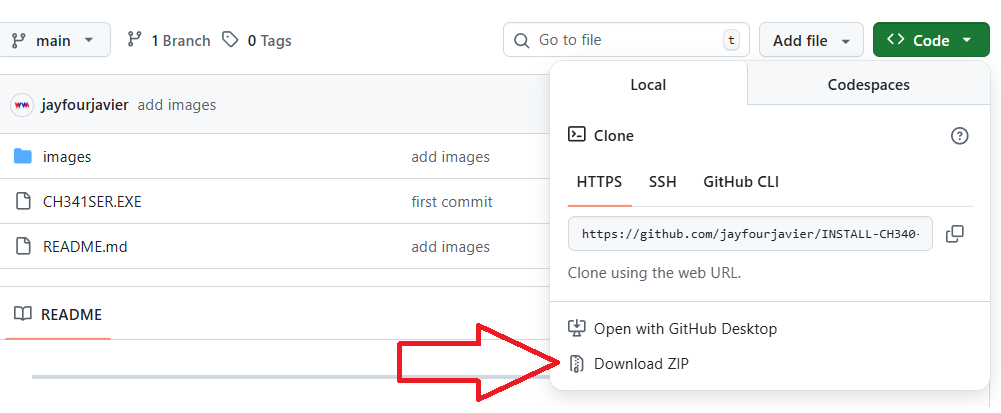
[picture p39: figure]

10. Установите драйвер.
11. Подключите MTL-1, используя кабель USB-C, к персональному компьютеру.

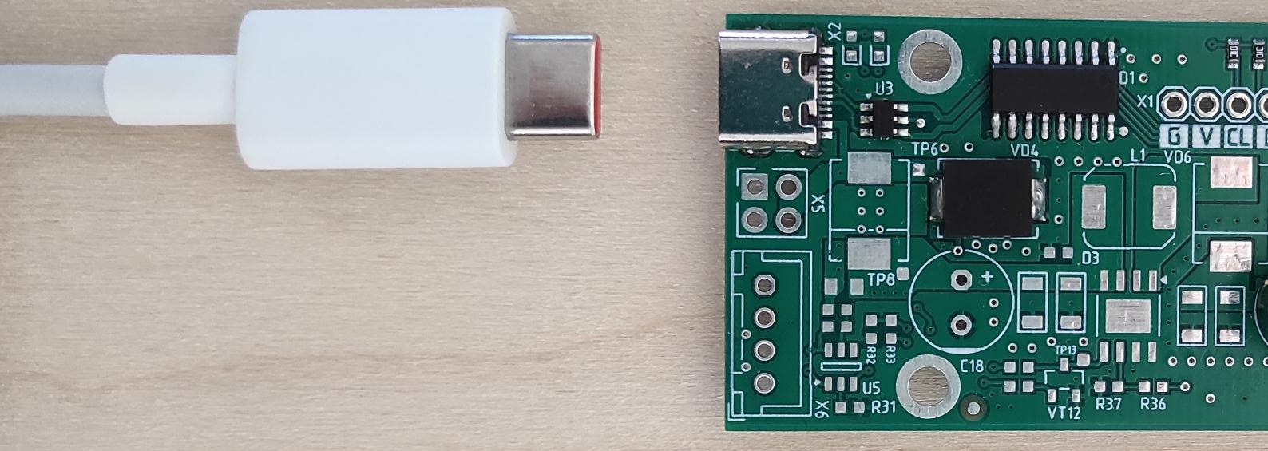
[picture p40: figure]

12. Откройте Диспетчер устройств. Убедитесь, что драйвер установился и устройство обнаружено.

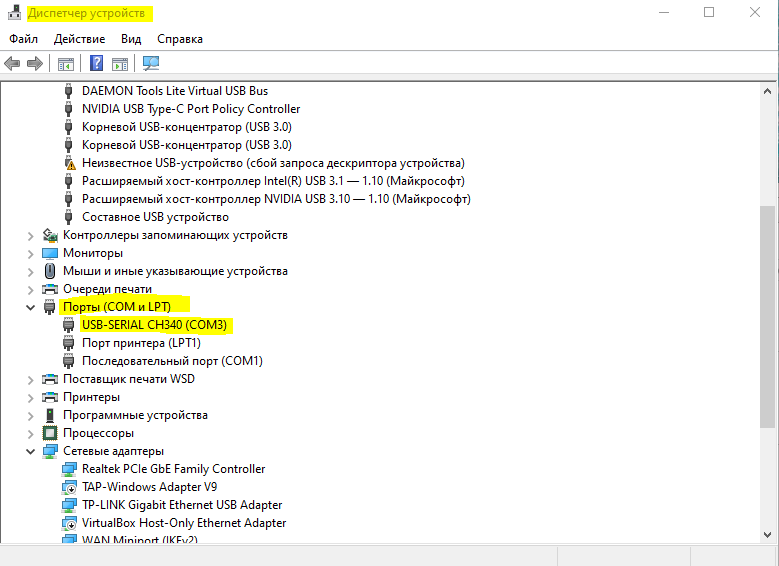
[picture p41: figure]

Установка Meshcore через Web Flasher

1. Убедитесь, что подключена антенна. Без антенны, включать устройство, категорически запрещено!
13. Зажмите кнопку BOOT (SB1), не отпуская кнопку, подключите USB-C к MTL-1

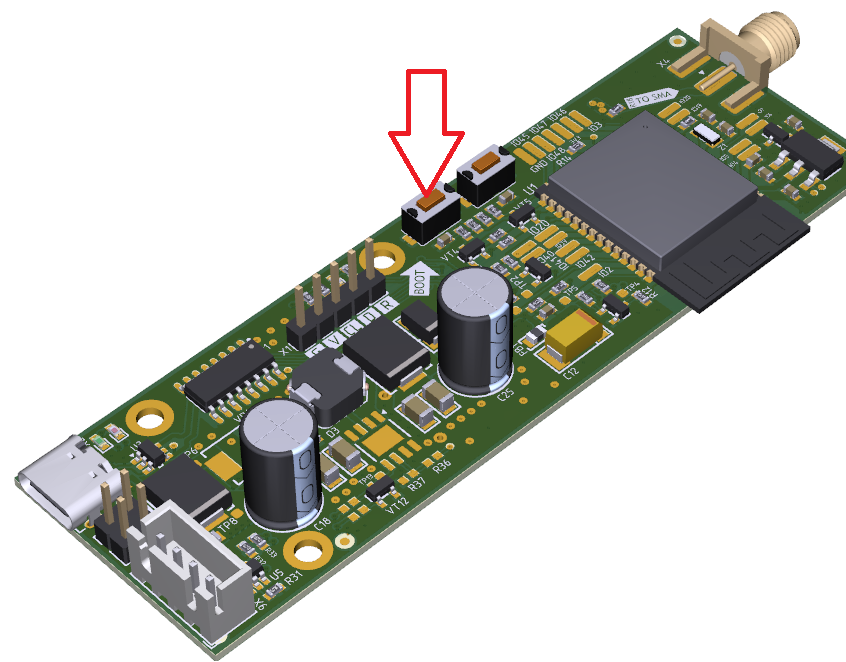
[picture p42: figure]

14. Откройте в браузере Google Chrome Web Flasher https://flasher.meshcore.dev/
15. Найдите и выберите Heltec v3 или Heltec WSL3
16. Выберите необходимую роль устройства
17. Выберите версию прошивки «Version». Если устройство прошиваете первый раз, установите флажок «Erase device» (Очистить память). Если обновляете ПО, то флажок устанавливать не нужно!

Нажмите вкладку Flash

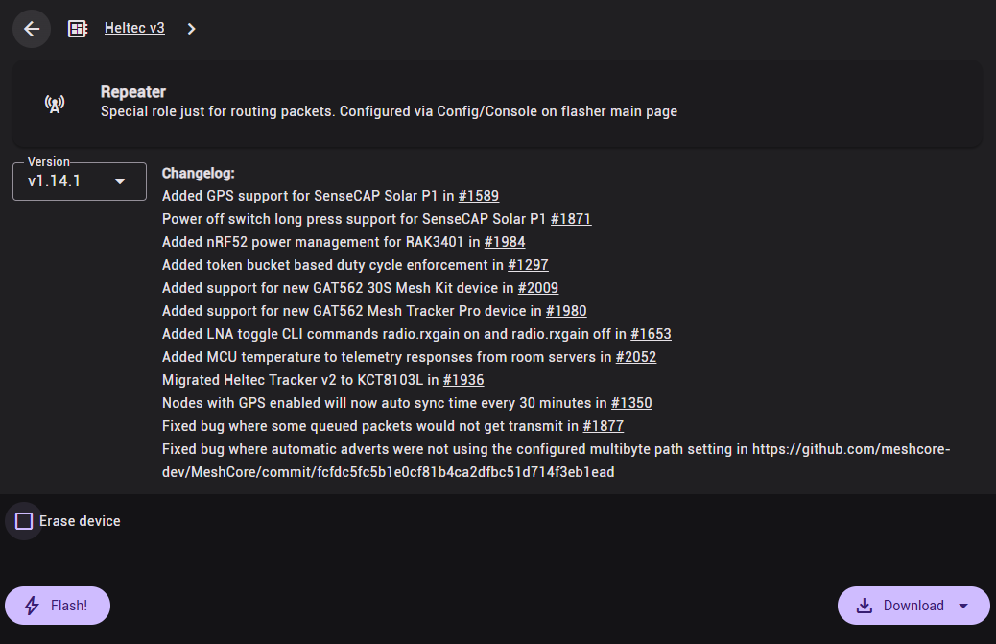
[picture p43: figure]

18. Выберите «USB Serial COM-port» к которому подключён MTL-1, затем нажмите «Подключение»

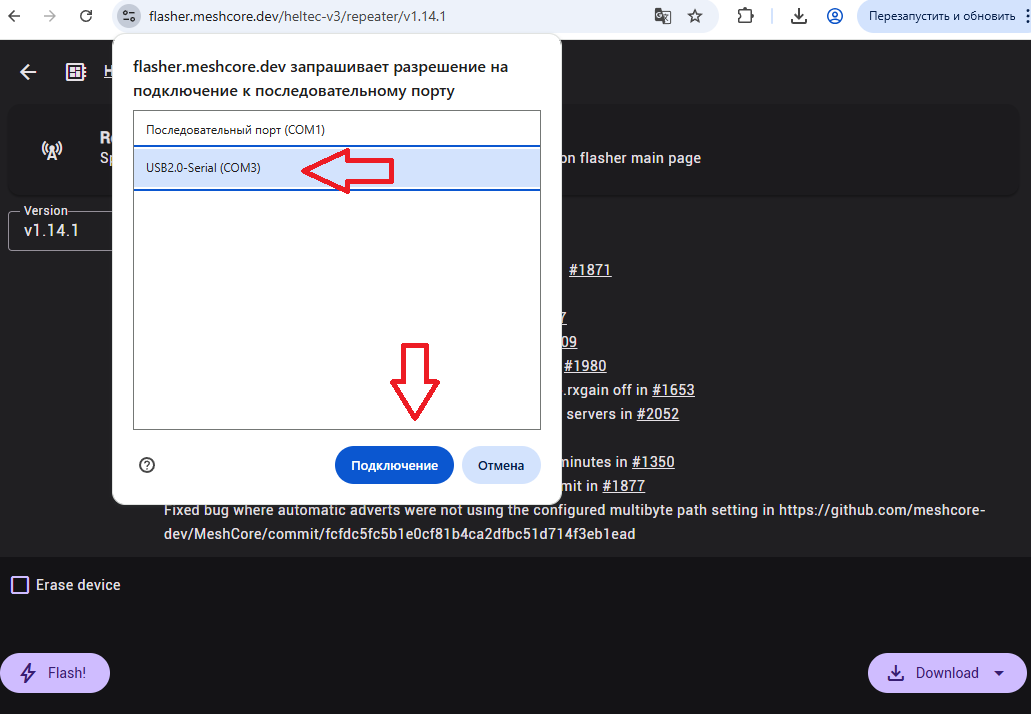
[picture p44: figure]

19. Ожидаем загрузку ПО 1-3мин

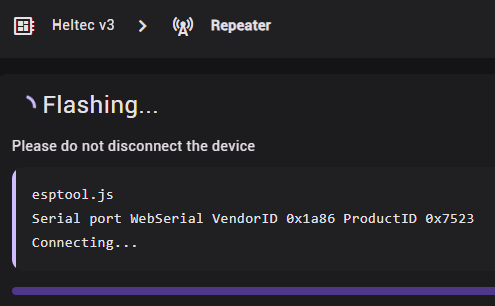
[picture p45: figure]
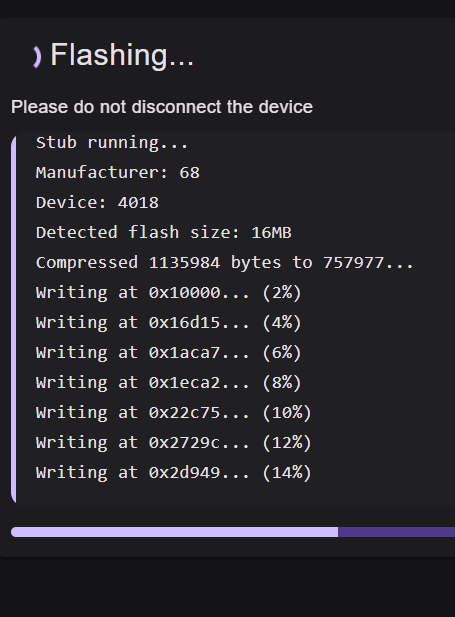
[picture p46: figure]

20. По завершению установки

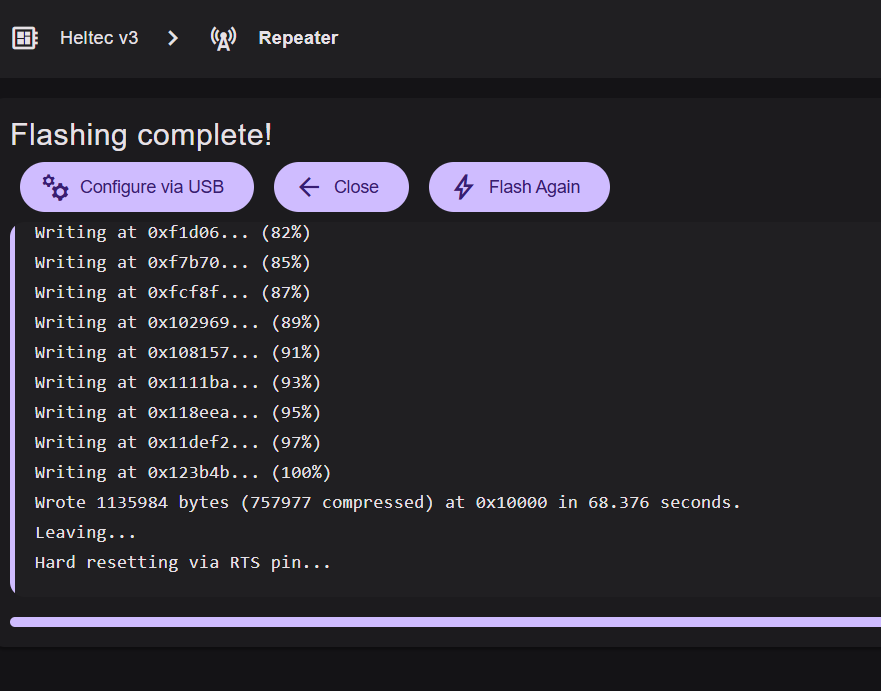
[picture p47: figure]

21. Перезагружаем устройство. Теперь можно приступать к конфигурации.

Установка Meshcore через Flash download tool

1. Загрузите Flash download tool (https://docs.espressif.com/projects/esp-test-tools/en/latest/esp32/production_stage/tools/flash_download_tool.html) https://dl.espressif.com/public/flash_download_tool.zip
22. Распакуйте архив в удобную папку
23. Загрузите прошивку и распакуйте файлы прошивки в директорию Flash download tool, например:\flash_download_tool\MTL1

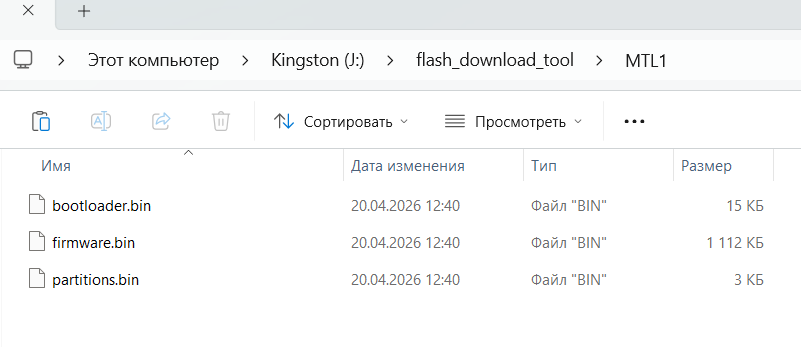
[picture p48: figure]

24. Запустите flash_download_tool
25. Уведомлении, нажмите «Подробнее»

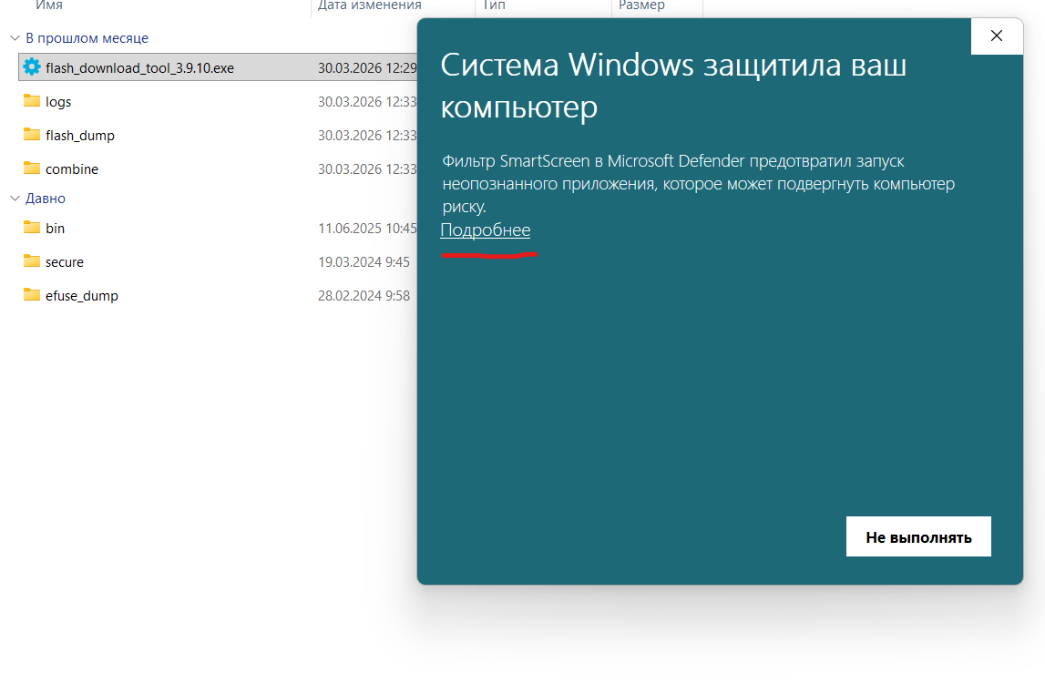
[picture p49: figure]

26. Подтвердите «Выполнить в любом случае»
27. Выберите параметры устройства:

Chip Type – ESP32-S3

WorkMode – Develop

LoadMode UART

28. Убедитесь, что подключена антенна. Без антенны, включать устройство, категорически запрещено!
29. Зажмите кнопку BOOT (SB1), не отпуская кнопку, подключите USB-C к MTL-1
30. Откройте окно «Flash tool download». Выберите COM-порт вашего устройства
31. Выберите файлы из архива прошивкой: bootloader.bin, partitions.bin, firmware.bin
32. Укажите адреса в hex формате, для файлов:

bootloader.bin 0x0

partitions.bin 0x8000

firmware.bin 0x10000

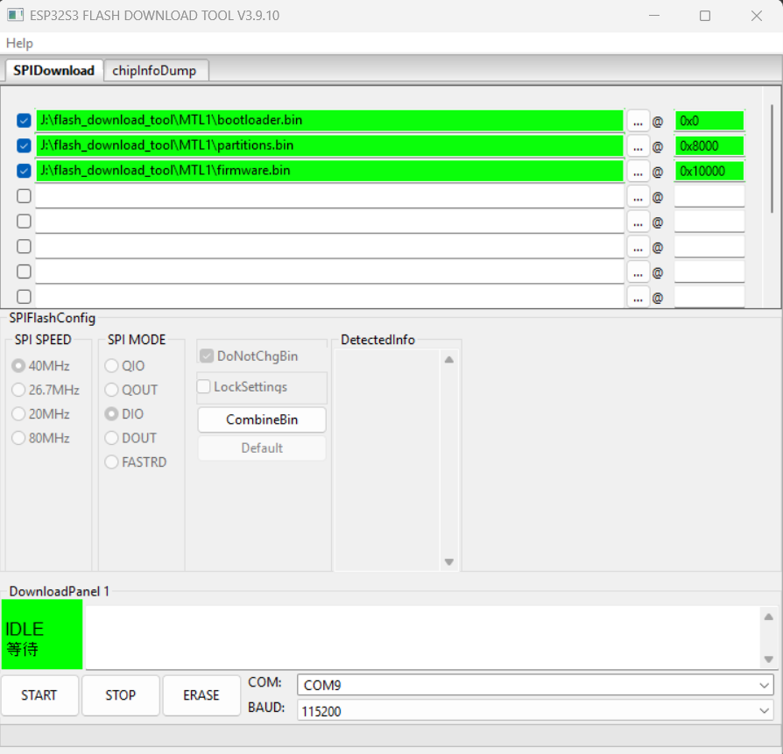
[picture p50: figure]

33. Если устанавливаете прошивку первый раз, то нажмите ERASE очистить память. В случае успеха, появится надпись FINISH
34. Для записи прошивки, нажать кнопку START

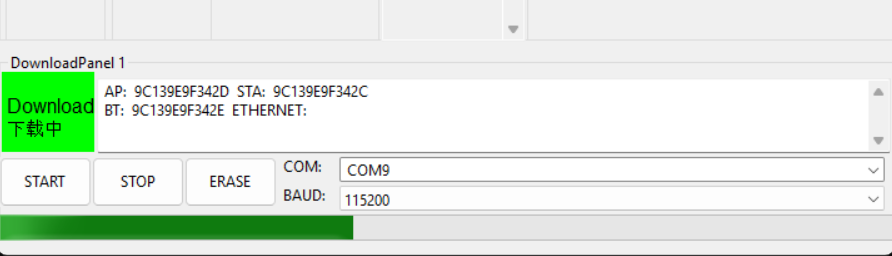
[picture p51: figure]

В случае успеха, появится надпись FINISH

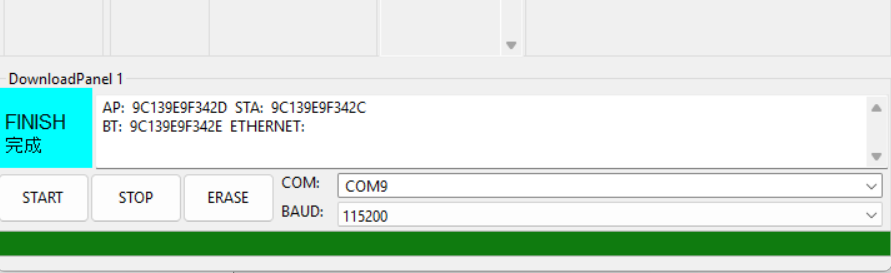
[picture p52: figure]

35. Перезагружаем устройство. Теперь можно приступать к конфигурации.

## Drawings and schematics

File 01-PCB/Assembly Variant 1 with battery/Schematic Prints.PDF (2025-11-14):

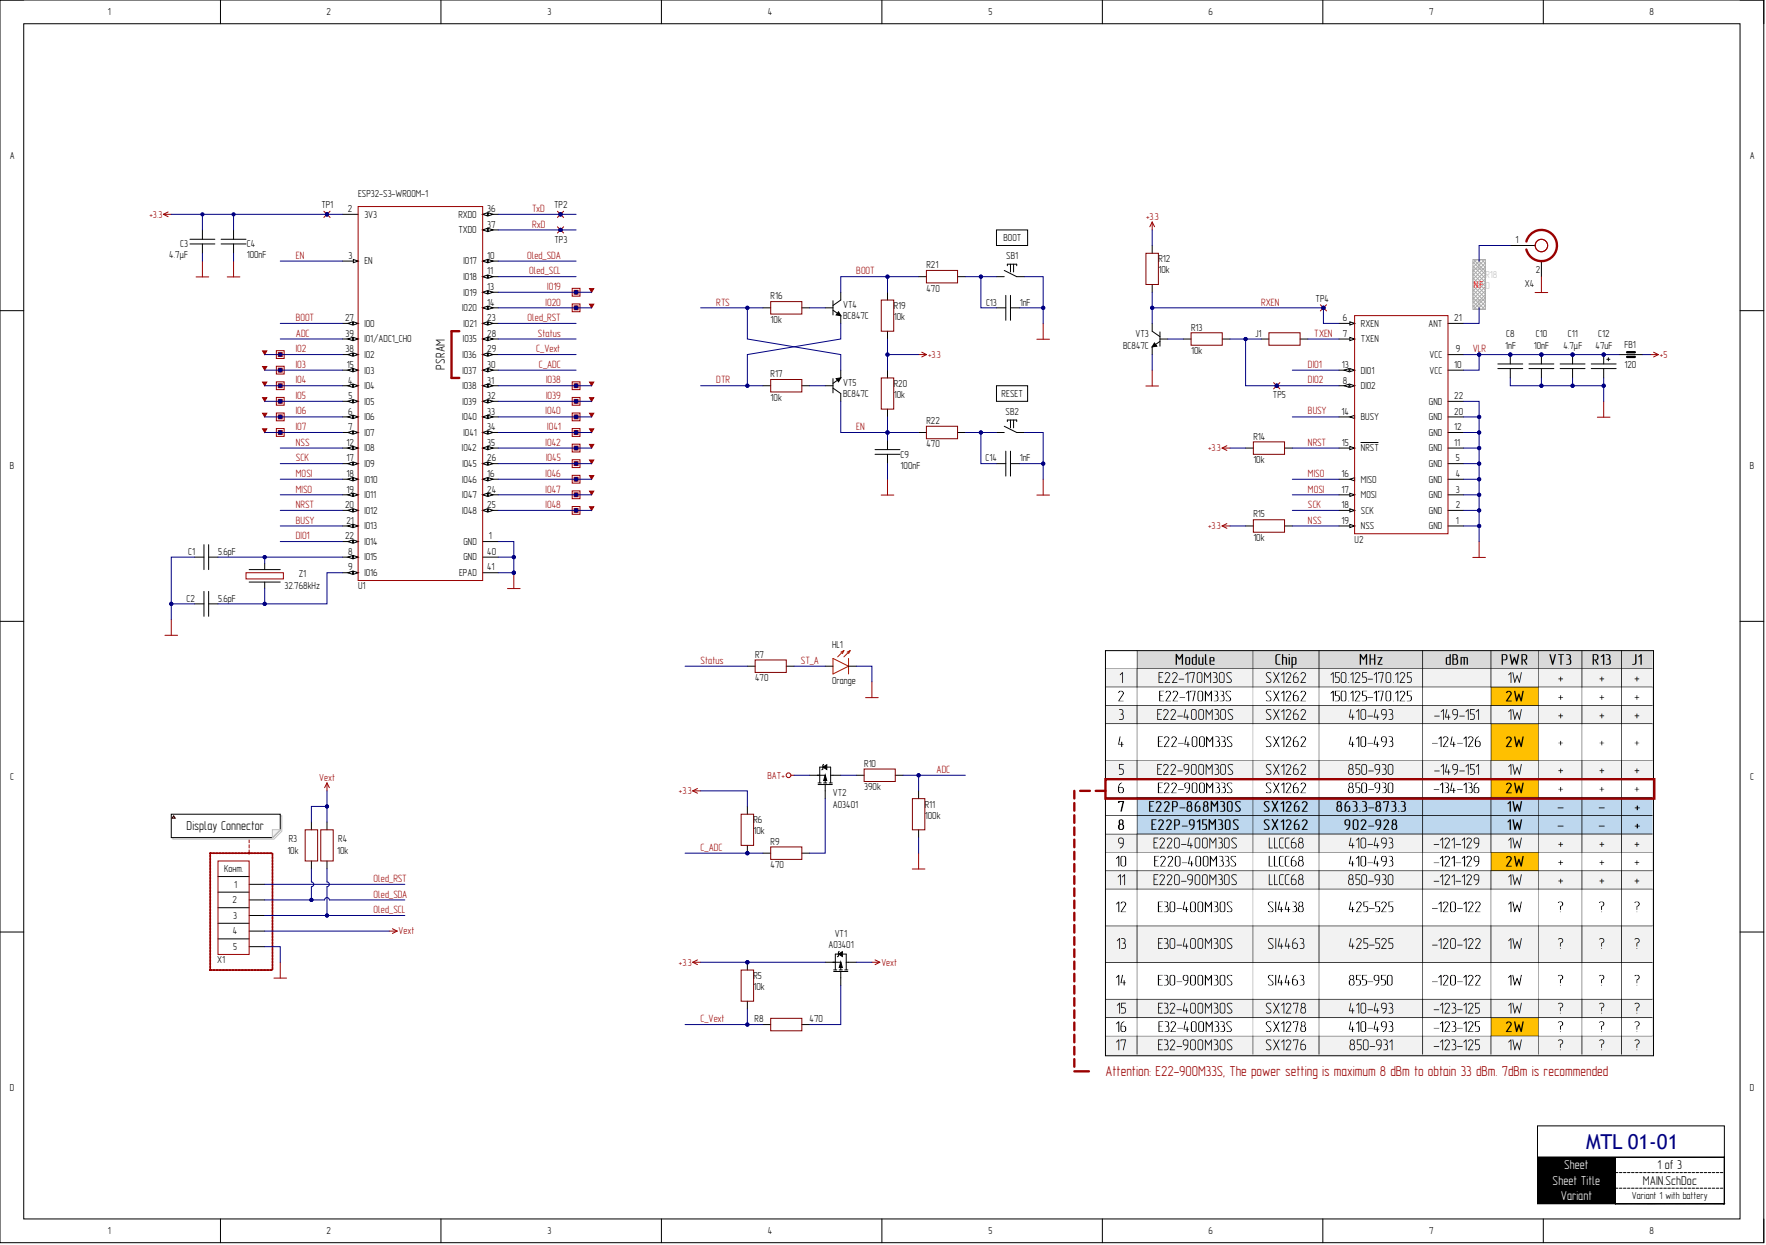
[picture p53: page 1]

DIO1 DIO2 | DIO1 13 DIO2 8

Attention: E22-900M33S, The power setting is maximum 8 dBm to obtain 33 dBm. 7dBm is recommended

Sheet | 1 of 3
Sheet Title | MAIN.SchDoc
Variant | Variant 1 with battery

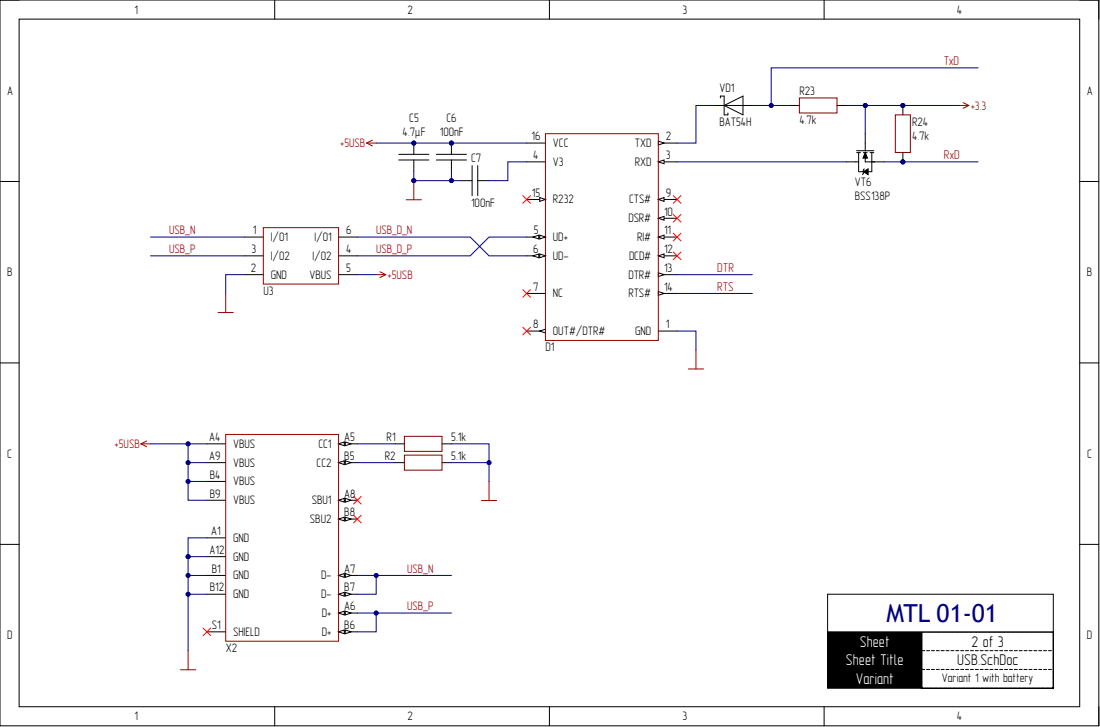
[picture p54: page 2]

Sheet | 2 of 3
Sheet Title | USB.SchDoc

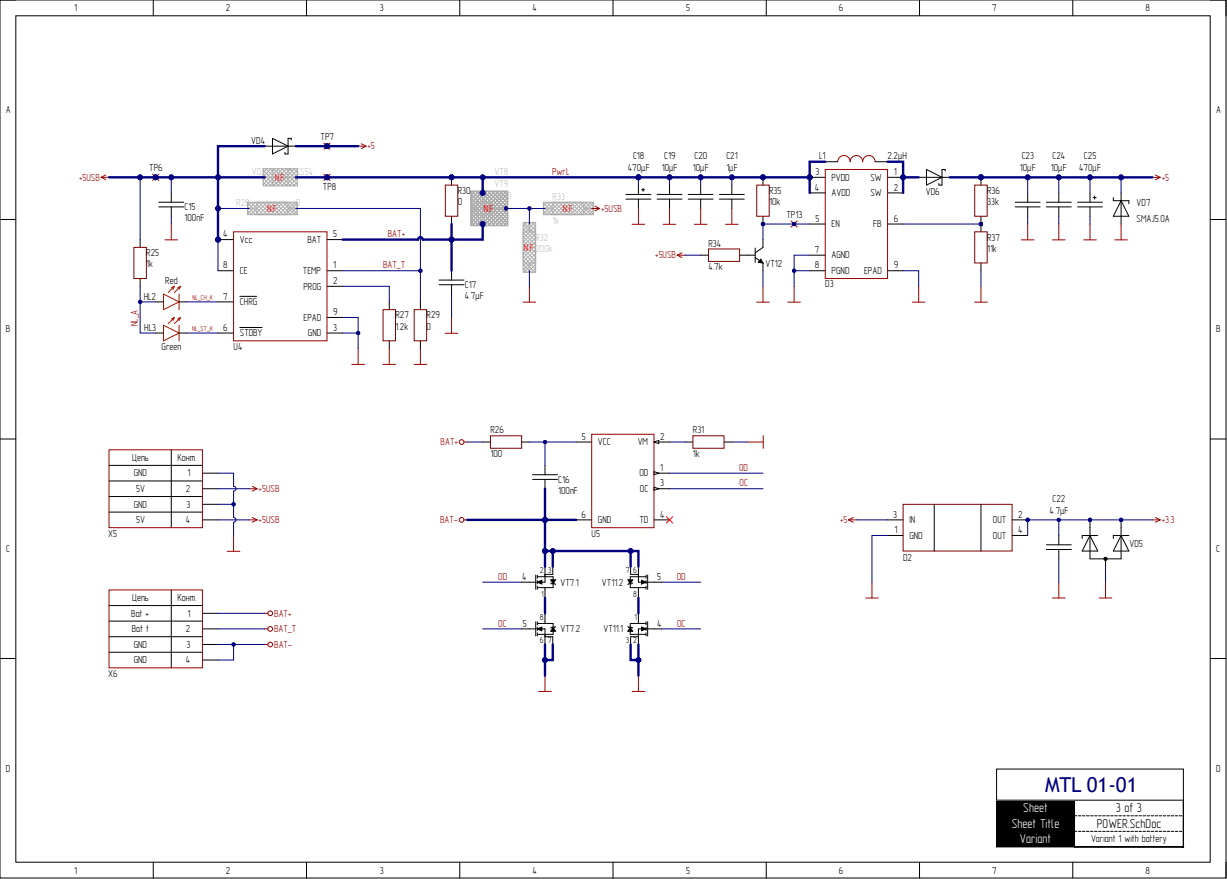
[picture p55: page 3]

HL3 | STDBY 6 GND

Цепь | Конт.
GND | 1
5V | 2
GND | 3
5V | 4

Bat + | 1
Bat t | 2
GND | 4

Sheet | 3 of 3
Sheet Title | POWER.SchDoc

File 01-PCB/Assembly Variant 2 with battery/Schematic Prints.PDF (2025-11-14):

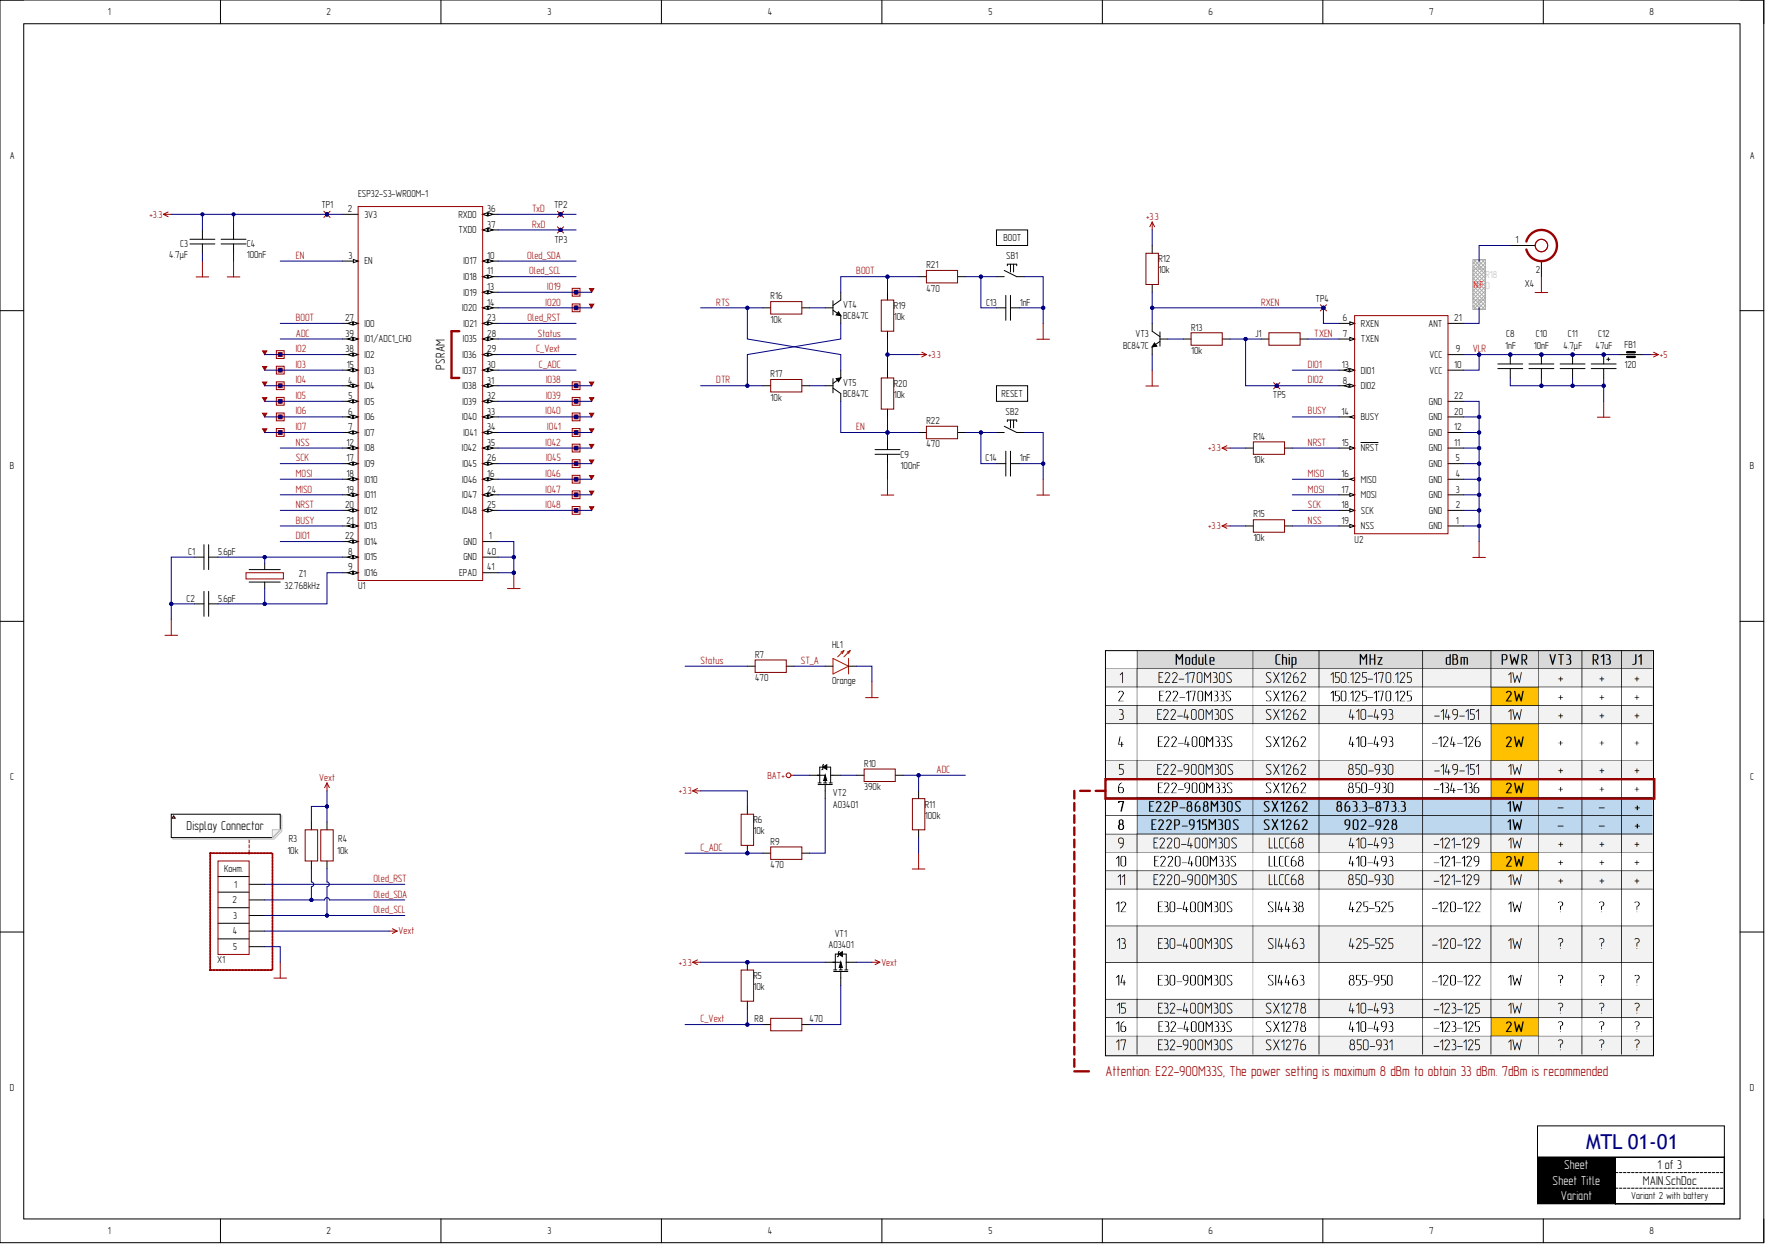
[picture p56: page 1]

DIO1 DIO2 | DIO1 13 DIO2 8

Attention: E22-900M33S, The power setting is maximum 8 dBm to obtain 33 dBm. 7dBm is recommended

Sheet | 1 of 3
Sheet Title | MAIN.SchDoc
Variant | Variant 2 with battery

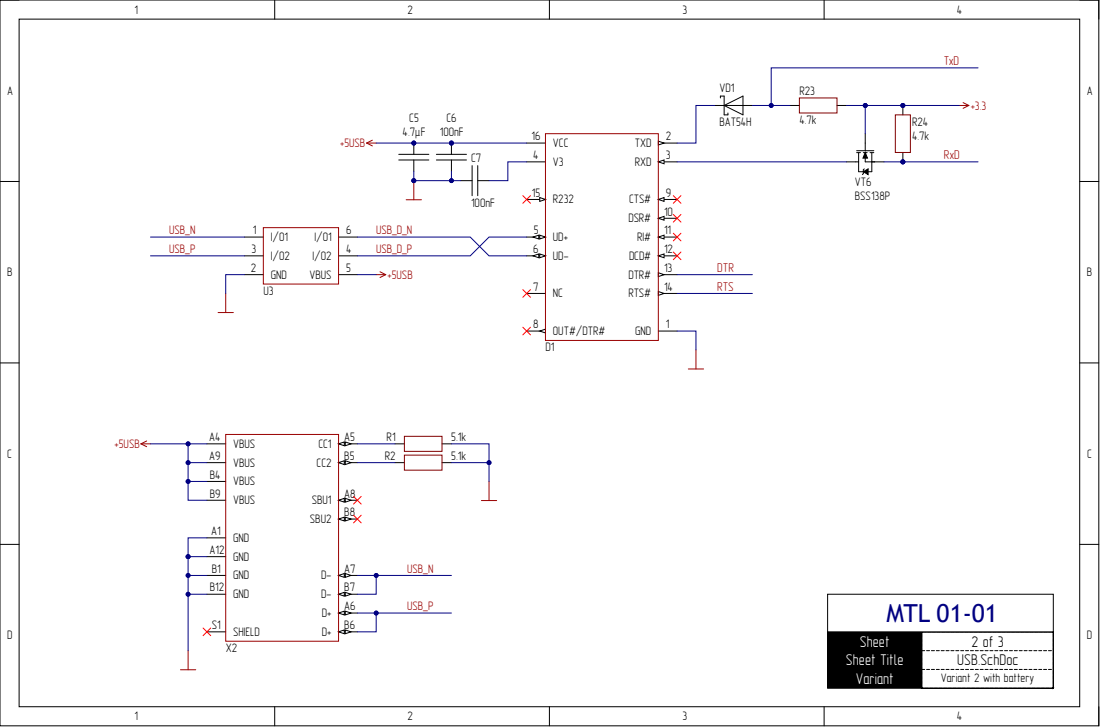
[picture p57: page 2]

Sheet | 2 of 3
Sheet Title | USB.SchDoc

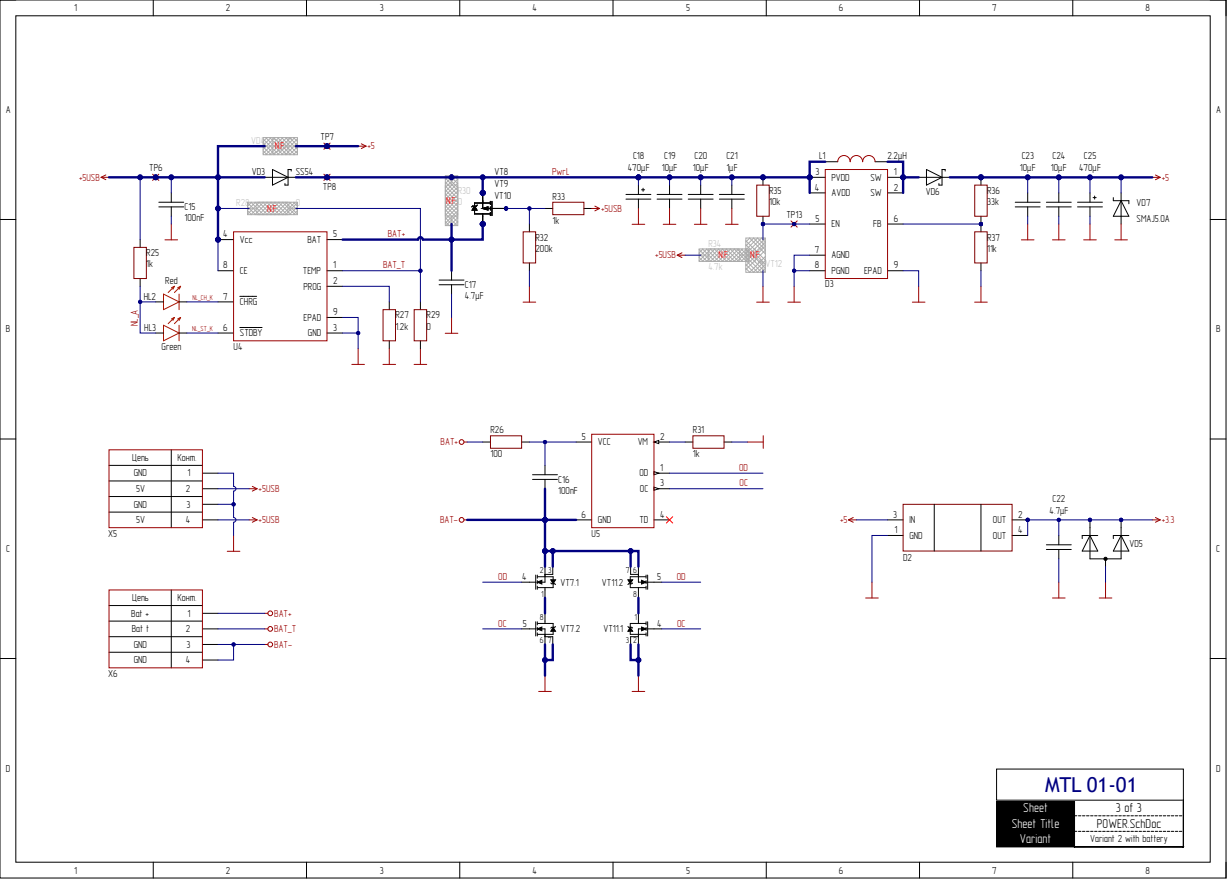
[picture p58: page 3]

BAT TEMP PROG | 5 Vcc 4

CE 8 | | 1 BAT_T
CHRG 7 | | 2

HL3 | | STDBY 6 GND

Цепь | Конт.
GND | 1
5V | 2
GND | 3
5V | 4

Bat + | 1
Bat t | 2
GND | 4

Sheet | 3 of 3
Sheet Title | POWER.SchDoc

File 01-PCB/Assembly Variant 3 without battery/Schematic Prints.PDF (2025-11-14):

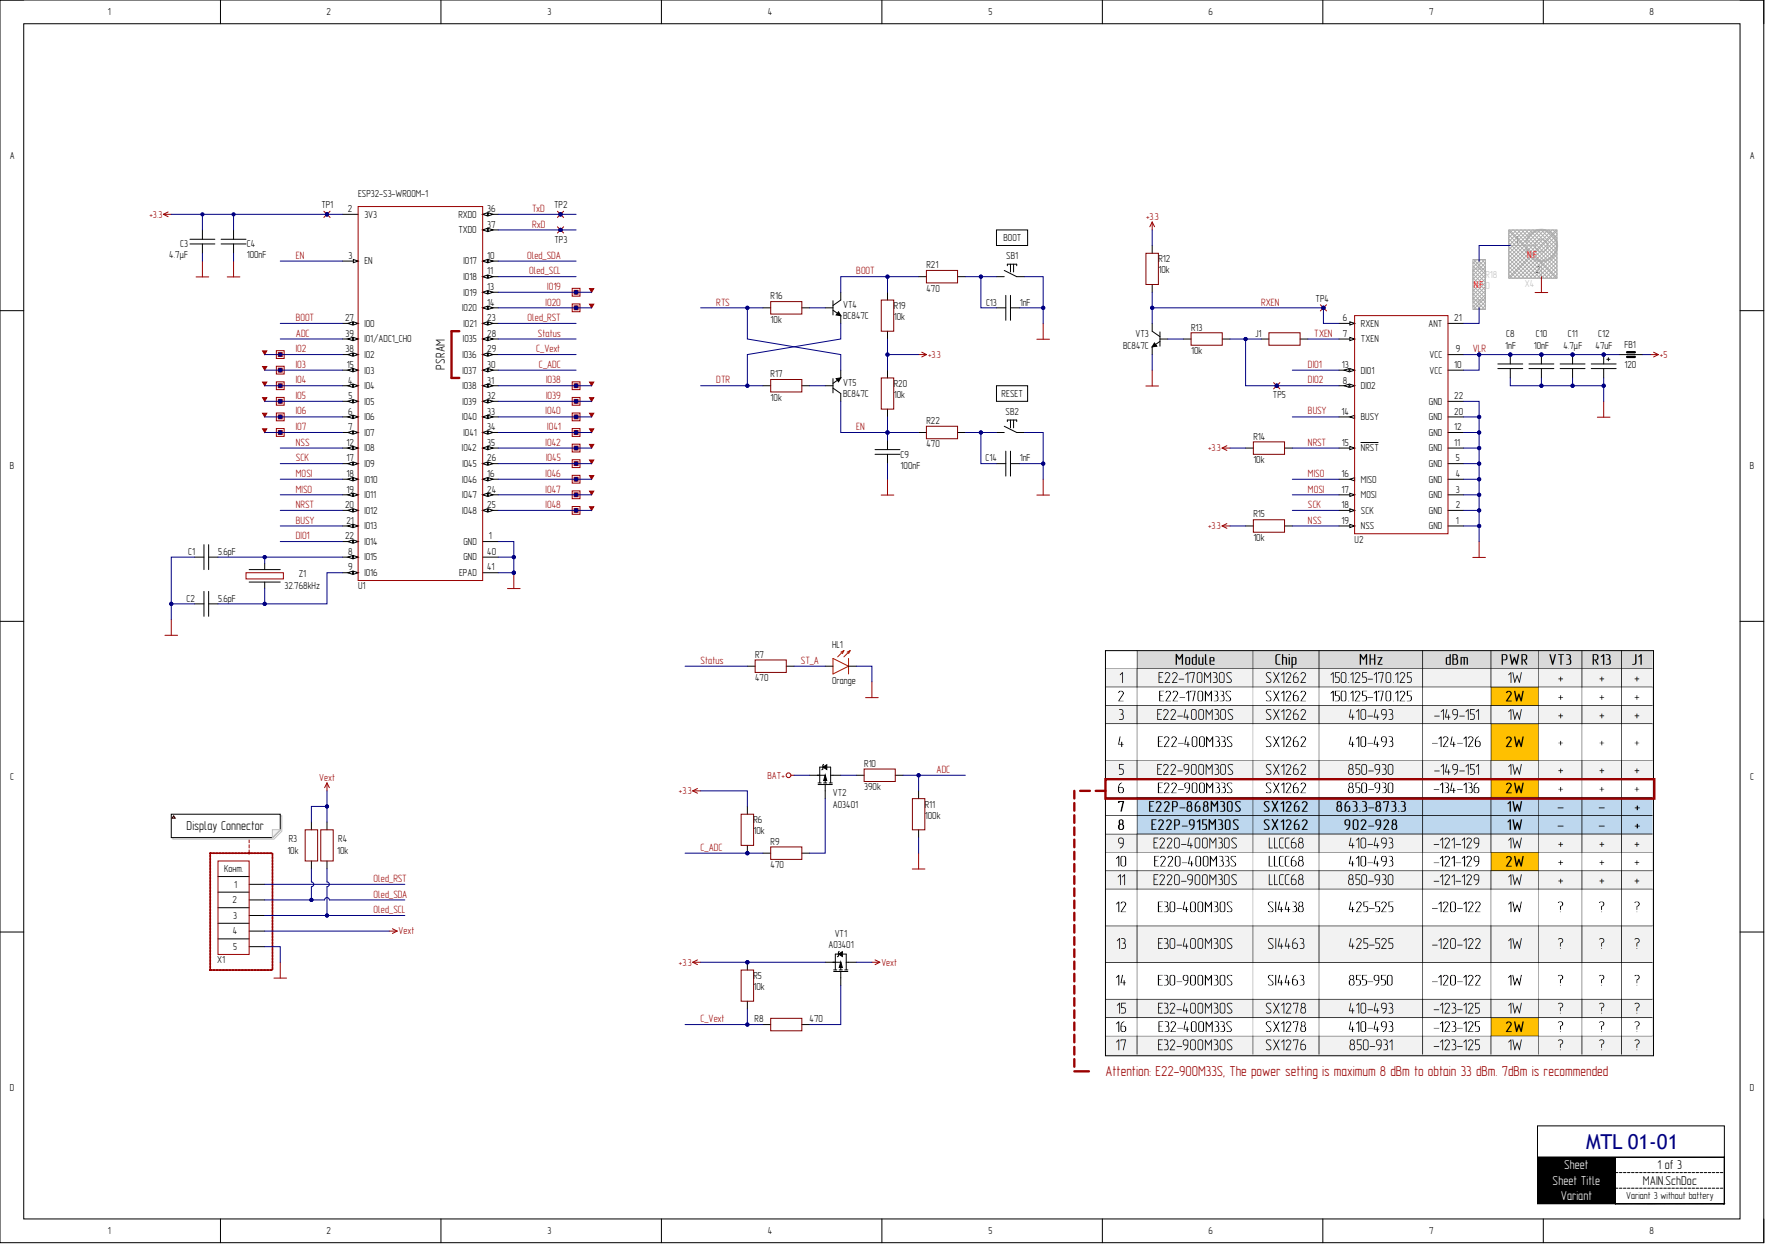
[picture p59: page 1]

DIO1 DIO2 | DIO1 13 DIO2 8

Attention: E22-900M33S, The power setting is maximum 8 dBm to obtain 33 dBm. 7dBm is recommended

Sheet | 1 of 3
Sheet Title | MAIN.SchDoc
Variant | Variant 3 without battery

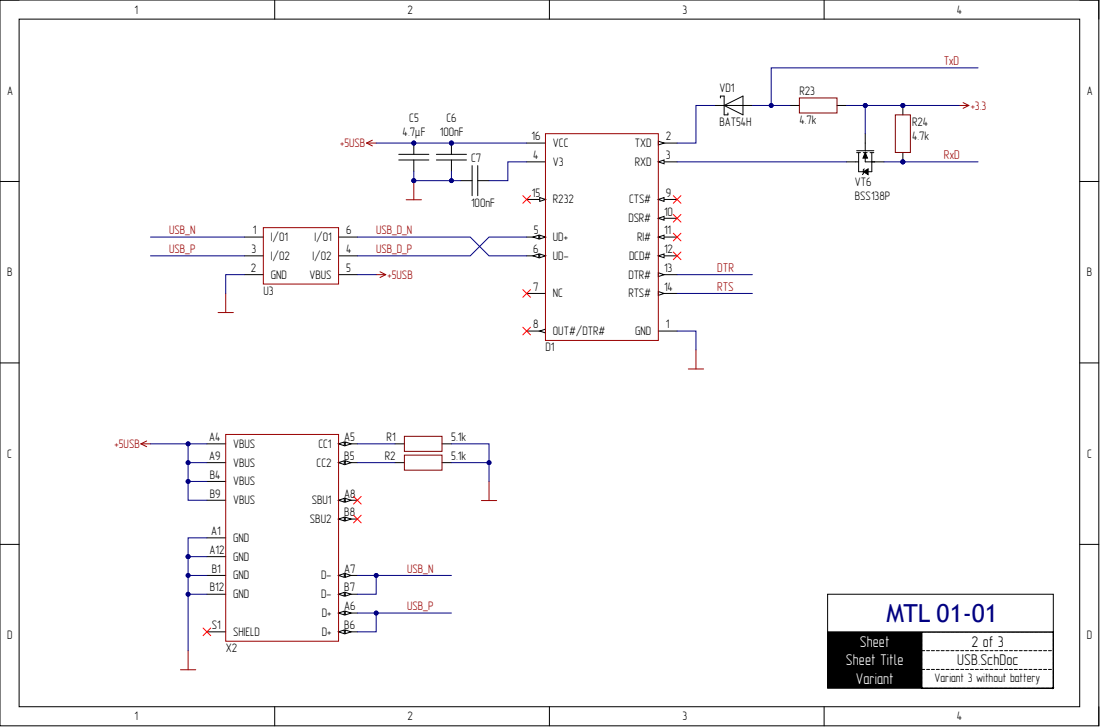
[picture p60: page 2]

Sheet | 2 of 3
Sheet Title | USB.SchDoc

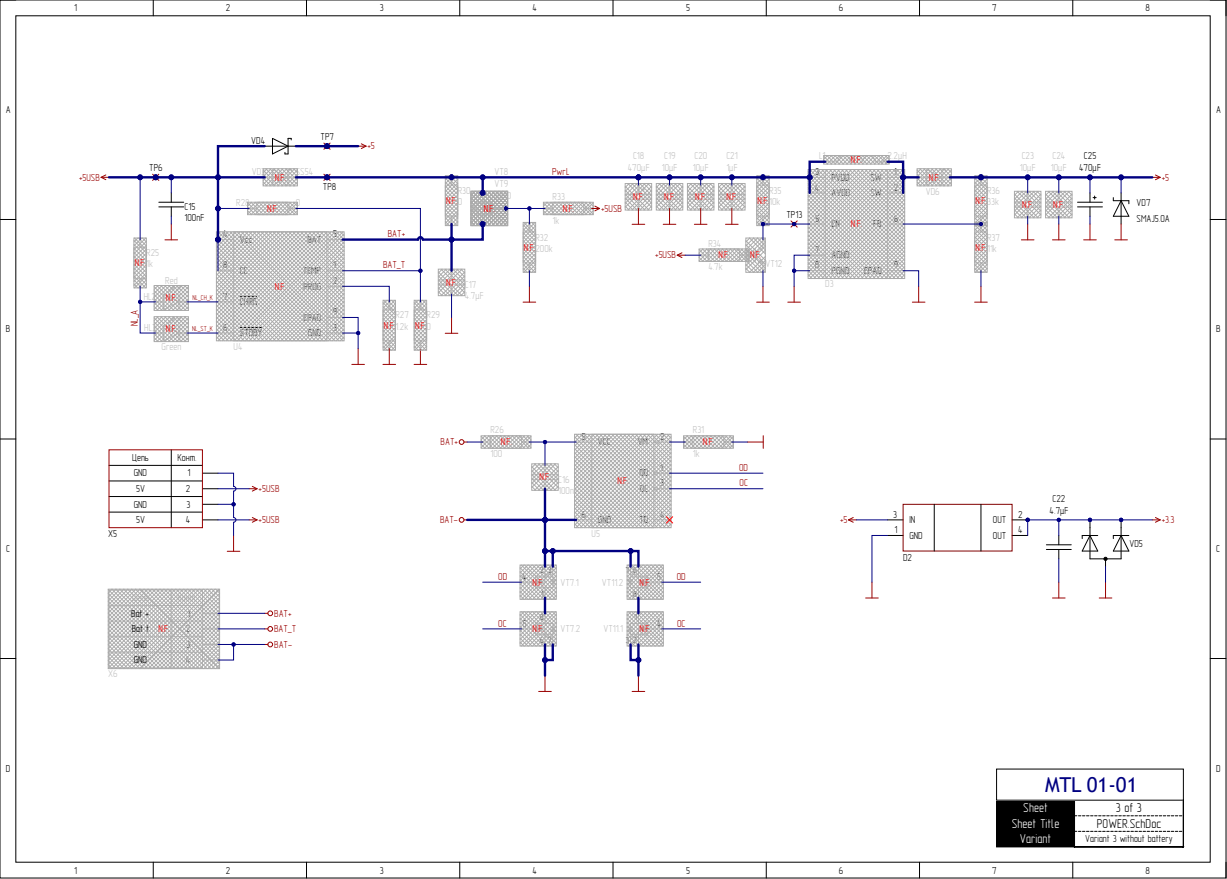
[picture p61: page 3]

EPAD STDBY 6 GND | 9

Цепь | Конт.
GND | 1
5V | 2
GND | 3
5V | 4

Bat + | 1
Bat t N.F. | 2

Sheet | 3 of 3
Sheet Title | POWER.SchDoc

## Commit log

2025-11-14 Add rev1 MTL
    add rev1
    [Gerber_Copper_Signal_Bot.gbr, Gerber_Copper_Signal_Top.gbr, Gerber_Legend_Bot.gbr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]
2026-05-23 add mounting panel
    [Z10-7_158х90х60.3mf, Z10-7_158х90х60.SLDASM, Z10-7_158х90х60.STL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]
2026-06-15 add pic case
2026-07-30 add flash_download_tool
    [Шасси2.SLDPRT, Шасси2.STL]
2026-10-31 add Case Tube 40mm
2026-10-31 add pic tube
